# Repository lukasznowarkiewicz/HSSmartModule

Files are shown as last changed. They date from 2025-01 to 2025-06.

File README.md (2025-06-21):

# HSSmartModule

HSSM-3d-model

## Overview

This repository contains design files of Home Span Smart Module. The device is intended to use with existing electrical installation as a light controller. Initially intended to be flashed with Home Span firmware and  use with Apple Home Kit ecosystem. This will allow basic support of the implement features like outputs control, reading states form the inputs and control from other devices - aka smart home in-wall module functionality. This will allow rather quick start of the desting of the device in the files and give chance to spot potential problems right away. In the future it is planned to create custom application, with support for all implemented features in hardware like power measurement, input from presence sensor and enabling thread radio communication. The device intentionally is divided into two PCBs. This will allow independent testing, of high voltage and low voltage parts. In the future will be possible to replace low voltage PCB with with another variant - equiped with another MCU, for example NRF52840. In the future after initial bringup, set of boards could be easily redesigned as single rigid-flex PCB. 

HSSM_module_and_prog_foto

## Features

- Powered form 230VAC mains voltage
- 2x output for controlling 230VAC devices, up to 4A per channel
- 3x 230VAC inputs - two intended for ordinary switches for direct control of the outputs, additional input for motion or presence sensor
- Power usage measurement using CS5480
- ESP32-C6 SOC as main MCU and radio module
- 8MB SPI flash memory 
- Wi-Fi 6, Bluetooth 5 LE, Thread (802.15.4), Zigbee
- U.FL antenna connector

## Block diagram

## Low Voltage PCB

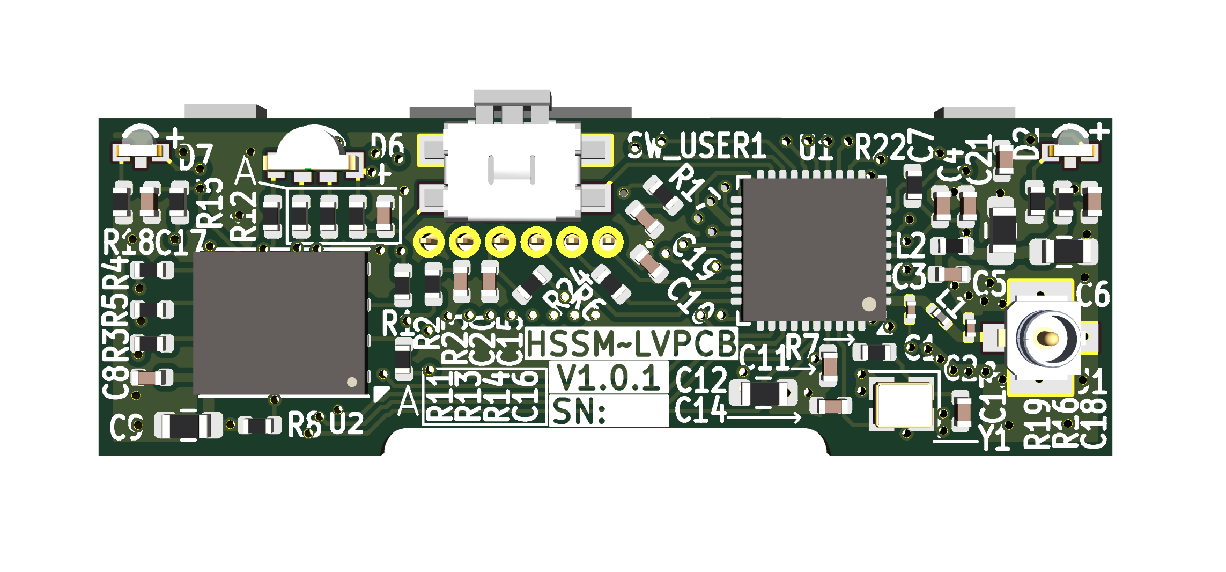
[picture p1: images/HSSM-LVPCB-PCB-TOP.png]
HSSM-LVPCB-PCB-TOP


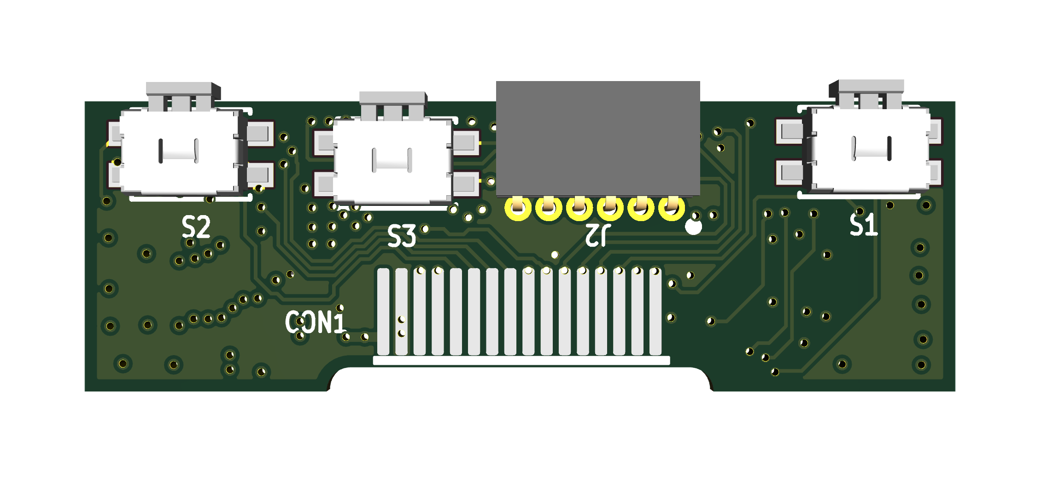
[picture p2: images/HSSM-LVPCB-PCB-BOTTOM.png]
HSSM-LVPCB-PCB-BOTTOM


### LVPCB Schematic

HSSM-LVPCB

- 3V3 power input - board is powered from HVPCB, or from programmer. If HVPCB is supplying power, 3V3 power jumper on HSSM-Prog should be left unconnected. 

- ESP32-C6 microcontroller - controlls outputs, reads values from inputs, controlls LEDs and communicate with other devices over thread, zigbee or wifi. All power inputs, crystal oscillator circuit, connection to SPI flash implemented according to datasheet.

- Antenna connector - allow connecting external 2.4 GHz antenna for wirelless connectivity

- SPI flash memory - stores ESP32-C6 program

- Additional switches and outs for debug - as program development with board powered from 230VAC seems risky, added additional switches and LEDs representing inputs and outputs on HVPCB. With those program development is possible, even without HVPCB, while LVPCB beeing powered from 3V3 LDO on programming board. 

- Programming connector - to connect HSSM-Prog, enables UART communication and puting ESP32-C6 into programming mode

- Edge connector - allows HSSM-FCB to be soldered to and connect HVPCB

## High Voltage PCB

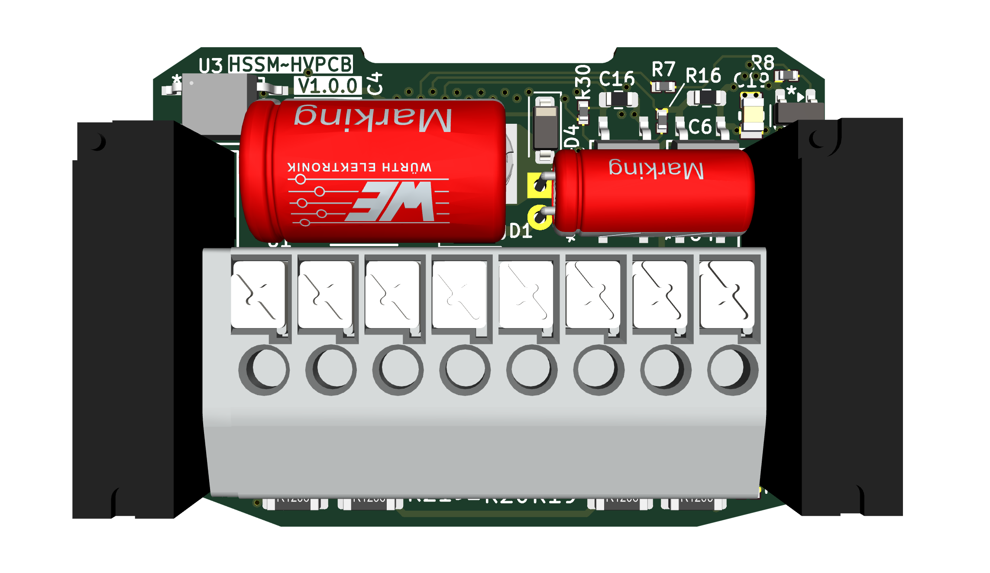
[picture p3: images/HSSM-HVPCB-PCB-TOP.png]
HSSM-HVPCB-PCB-TOP


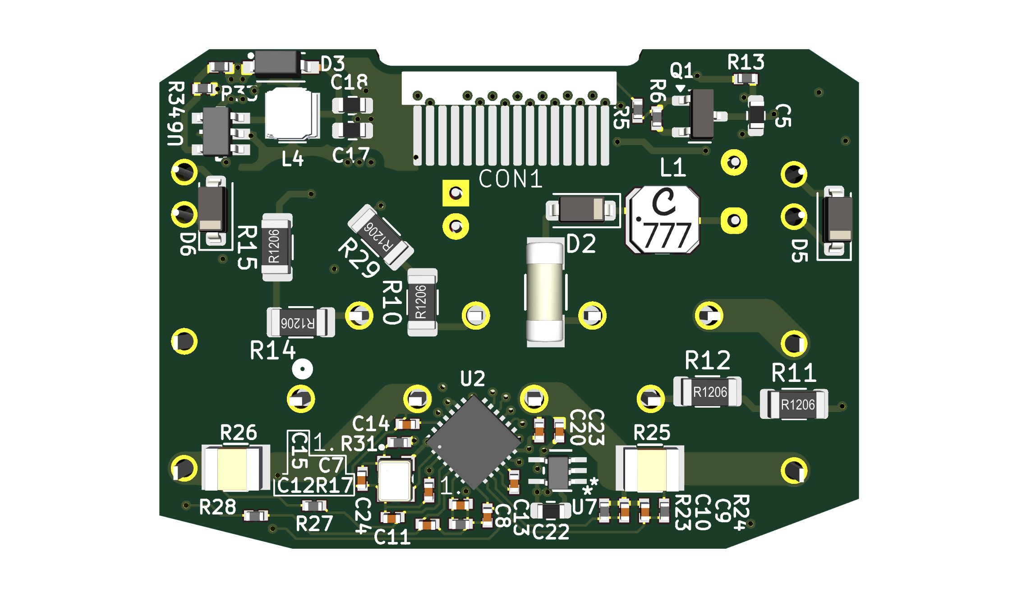
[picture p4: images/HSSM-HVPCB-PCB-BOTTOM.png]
HSSM-HVPCB-PCB-BOTTOM


<!-- ![HSSM-HVPCB-PCB-BOTTOM-IZO](images/HSSM-HVPCB-PCB-BOTTOM-IZO.png)
![HSSM-HVPCB-PCB-TOP-IZO](images/HSSM-HVPCB-PCB-TOP-IZO.png)
![HSSM-HVPCB-PCB-TOP-IZO2](images/HSSM-HVPCB-PCB-TOP-IZO2.png) -->
HSSM-HVPCB

Features:
- Outputs controls - two relays for switching 230VAC loads, internally connected to live wire terminal. Both relays powered from 12V 

- Input switches - three 230VAC inputs - for 

- 230VAC to 12VDC

- 12VDC to 3V3VDC converter

- Power measurement

## Flexible circuit board

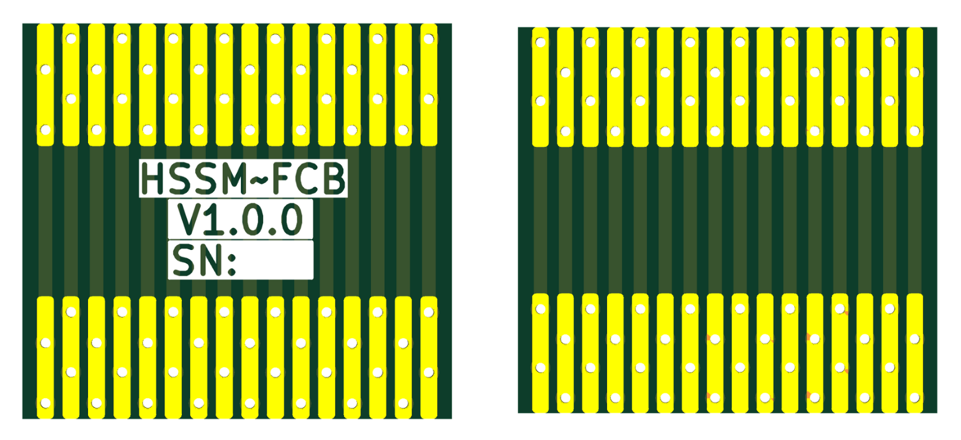
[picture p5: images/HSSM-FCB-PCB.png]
HSSM-FCB-PCB


HSSM-FCB

## HSSmartModule Programmer

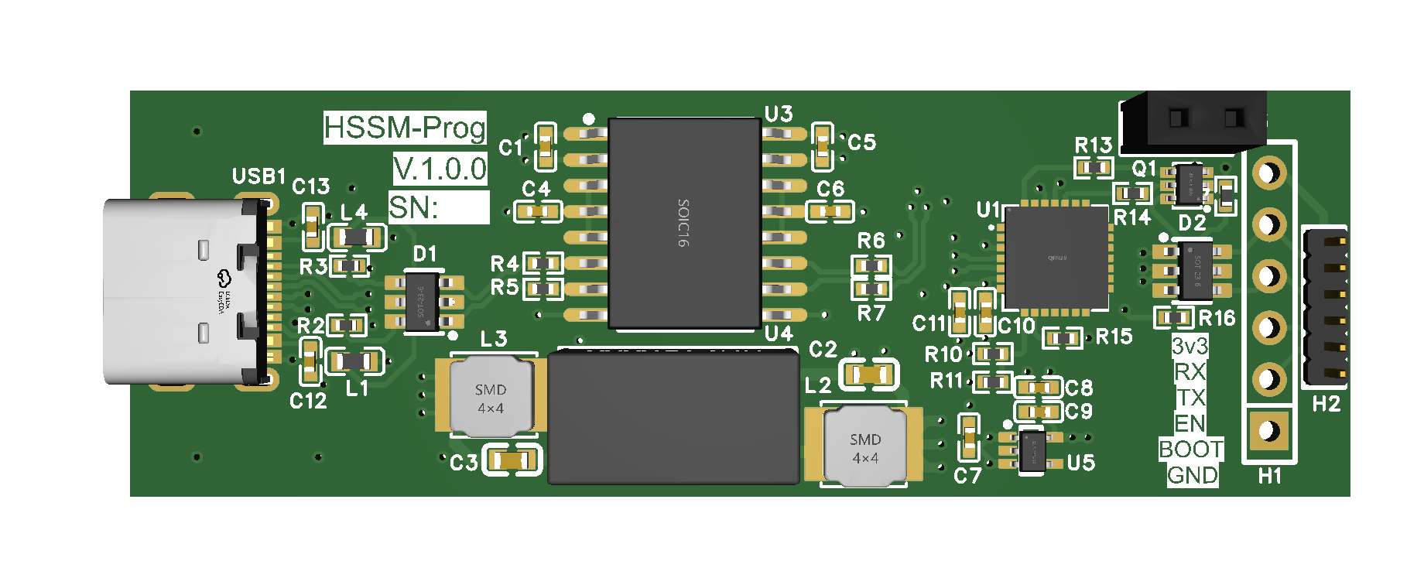
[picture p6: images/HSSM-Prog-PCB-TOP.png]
HSSM-Prog-PCB-TOP


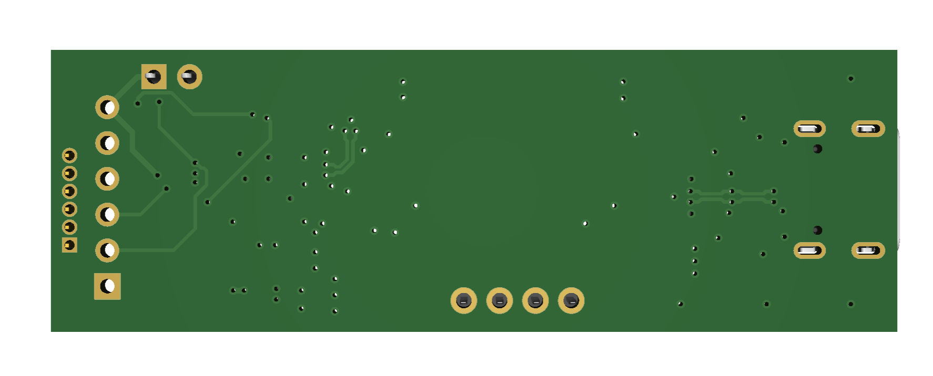
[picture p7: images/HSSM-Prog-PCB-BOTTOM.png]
HSSM-Prog-PCB-BOTTOM


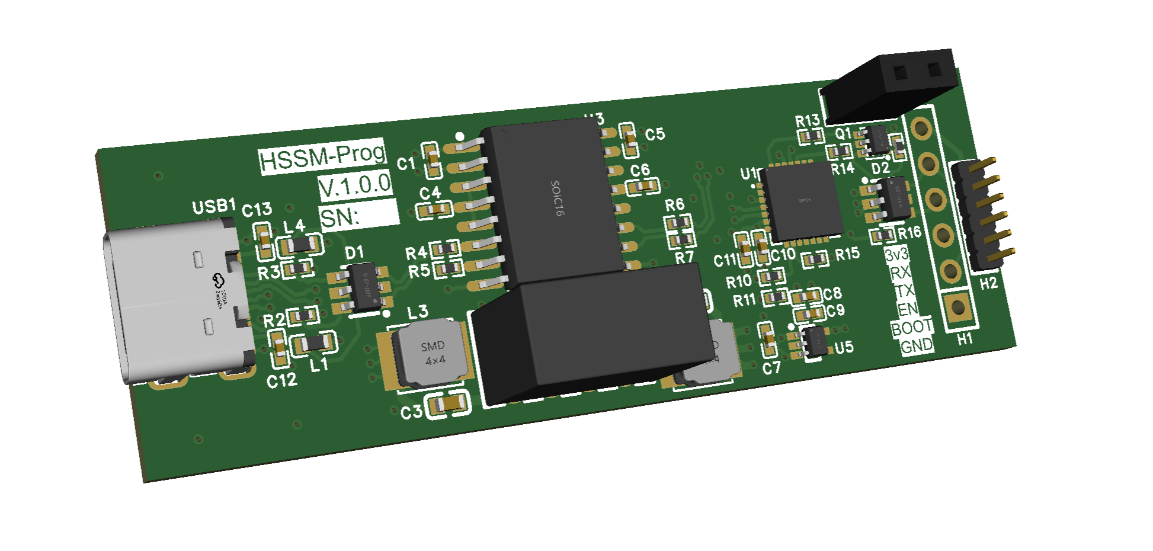
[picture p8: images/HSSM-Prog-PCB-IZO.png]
HSSM-Prog-PCB-IZO


HSSM-Prog-schematic

Features
- CP2102N USB UART converter
- Automatically put ESP32 chips into programming mode 
- power supply and data lines insulation 
- 6 poles 1.27 mm header and 6 poles 2.54 mm header for programming
- 3V3 voltage supplied to target MCU can be disable by removal of the jumper

## Manufacturing

All PCBs manufactured by JLCPCB, according to stackup set in each board's project.  

### HSSM-Prog

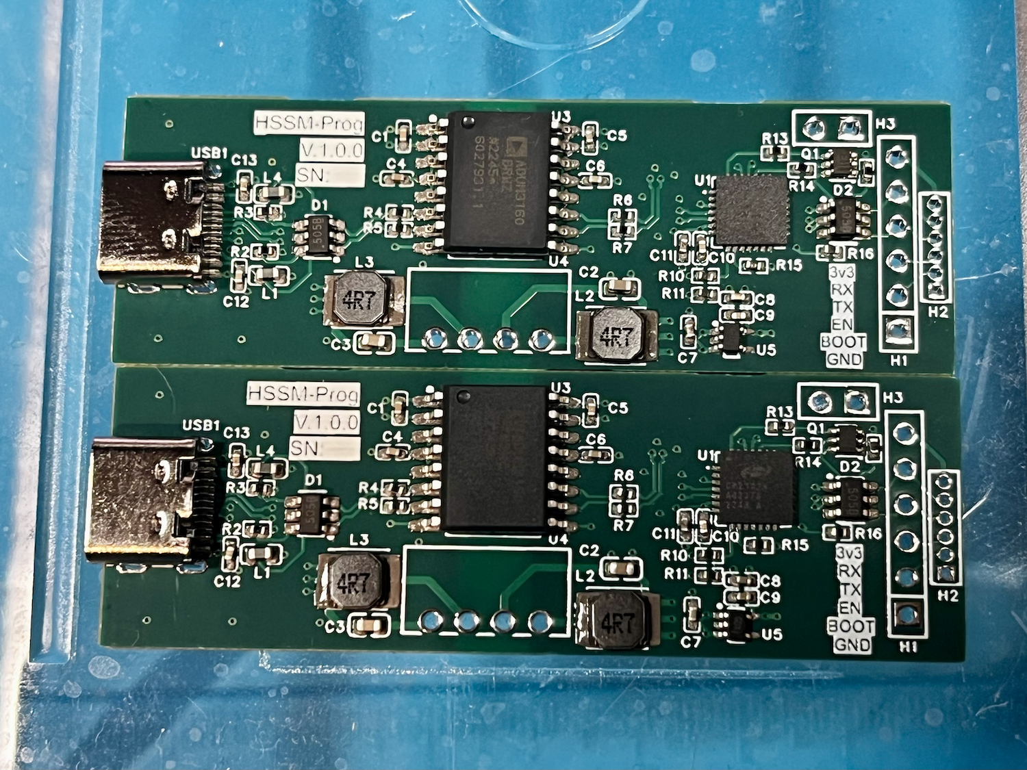
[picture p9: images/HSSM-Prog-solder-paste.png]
HSSM-Prog-solder-paste


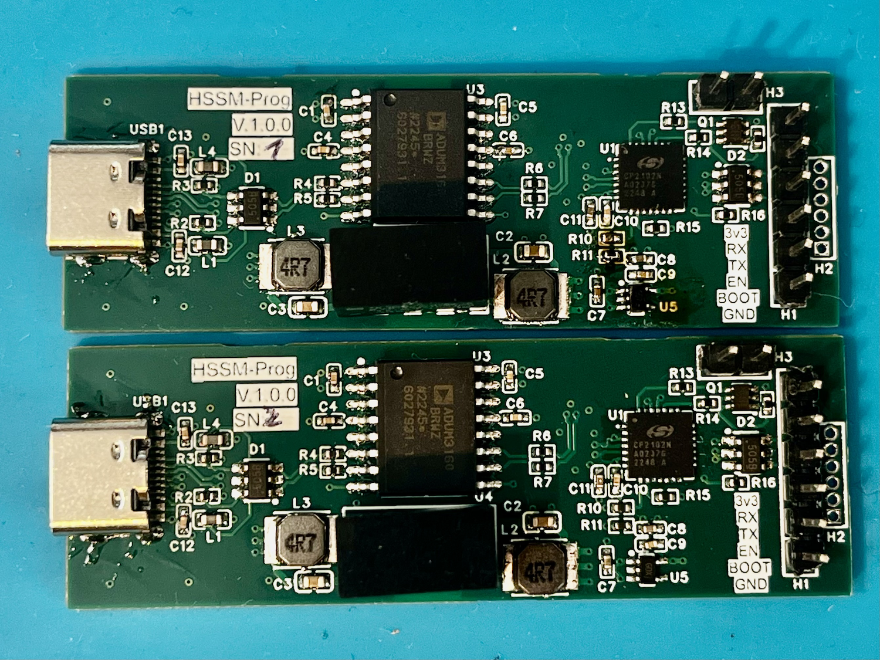
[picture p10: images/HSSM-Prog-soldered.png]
HSSM-Prog-soldered


### HSSM-LVPCB

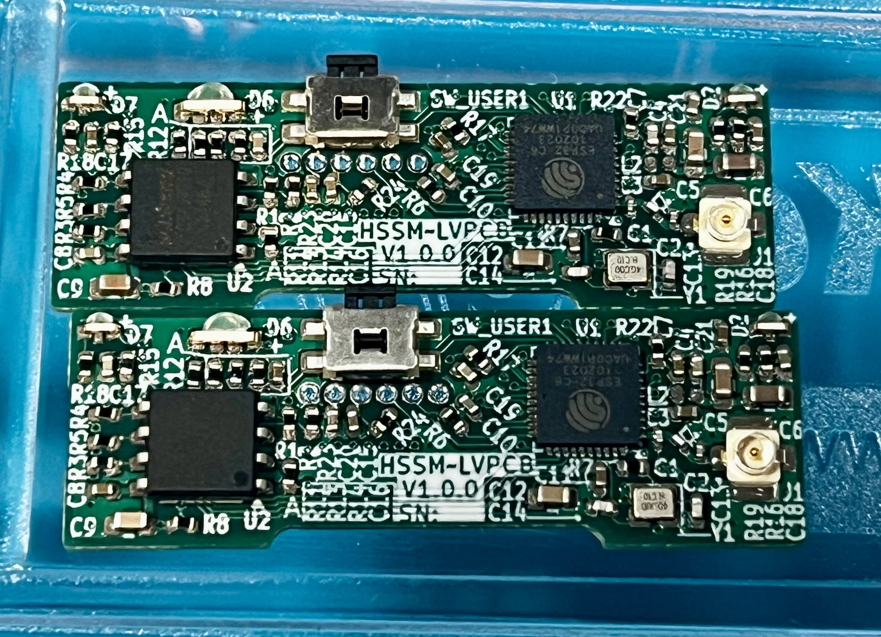
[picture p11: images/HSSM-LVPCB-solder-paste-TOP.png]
HSSM-LVPCB-solder-paste-TOP


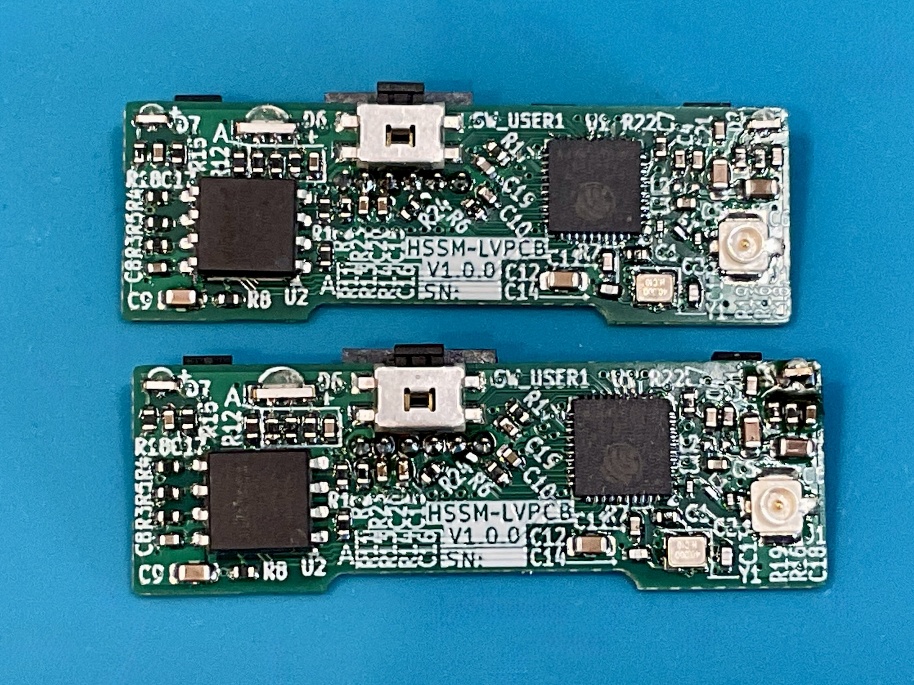
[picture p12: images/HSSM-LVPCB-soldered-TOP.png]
HSSM-LVPCB-soldered-TOP


### HSSM-HVPCB

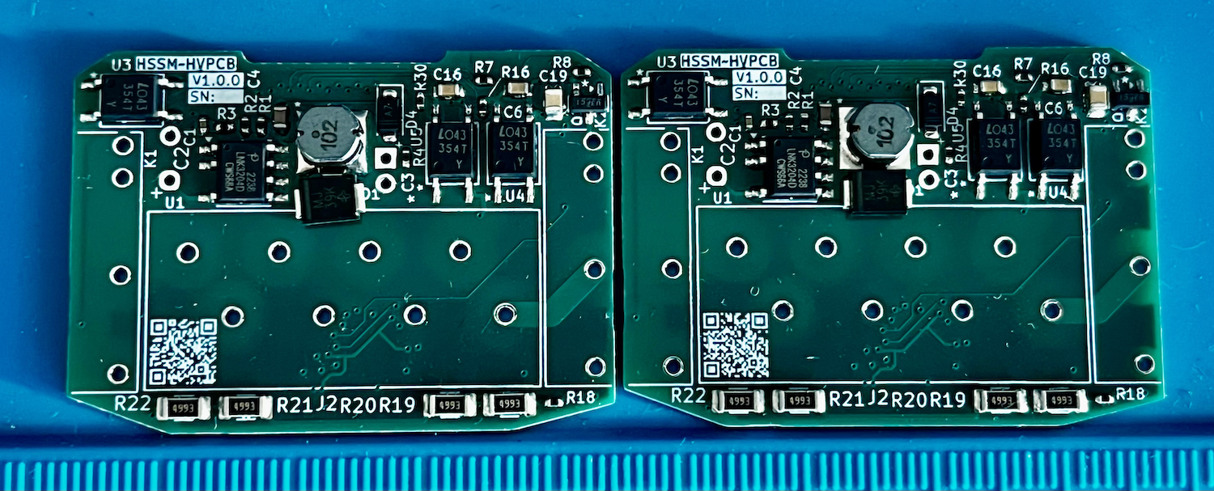
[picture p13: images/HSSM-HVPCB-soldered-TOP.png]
HSSM-HVPCB-soldered-TOP


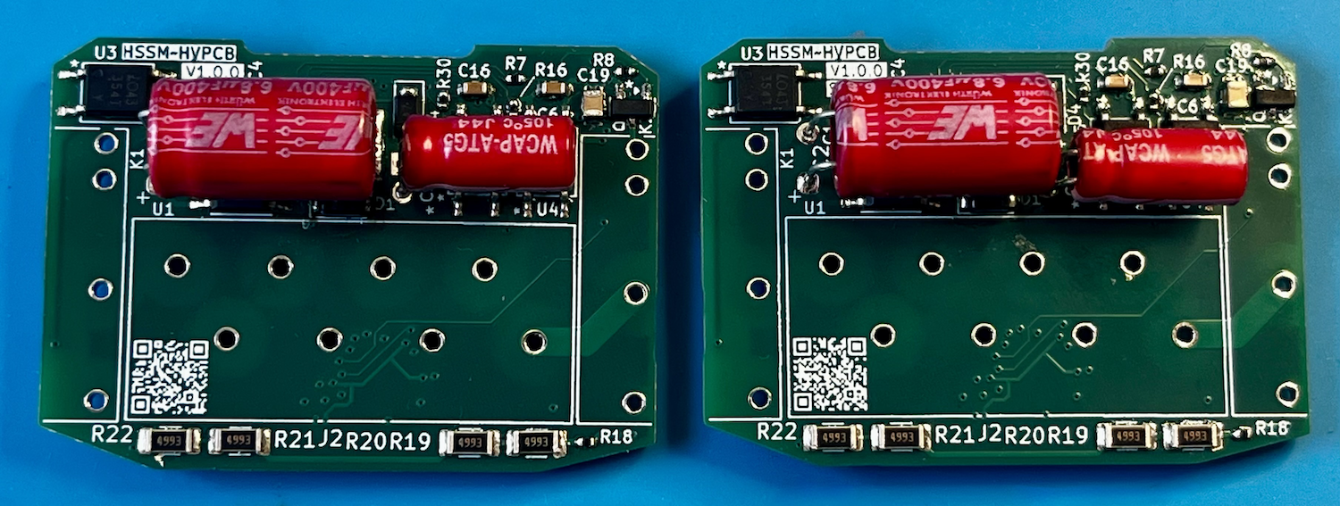
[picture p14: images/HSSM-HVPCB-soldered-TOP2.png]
HSSM-HVPCB-soldered-TOP2


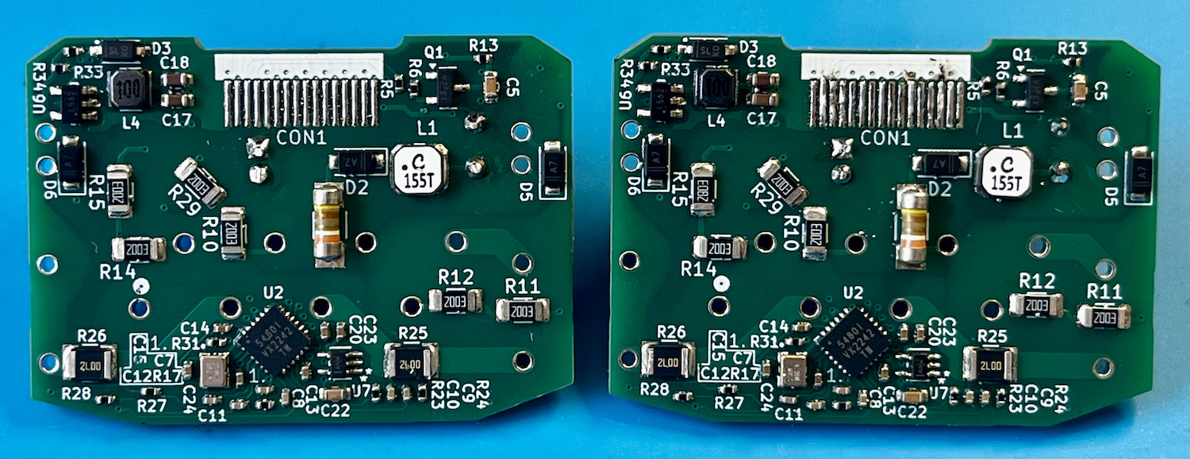
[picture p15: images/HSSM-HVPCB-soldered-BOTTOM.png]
HSSM-HVPCB-soldered-BOTTOM


## Boards bring up 

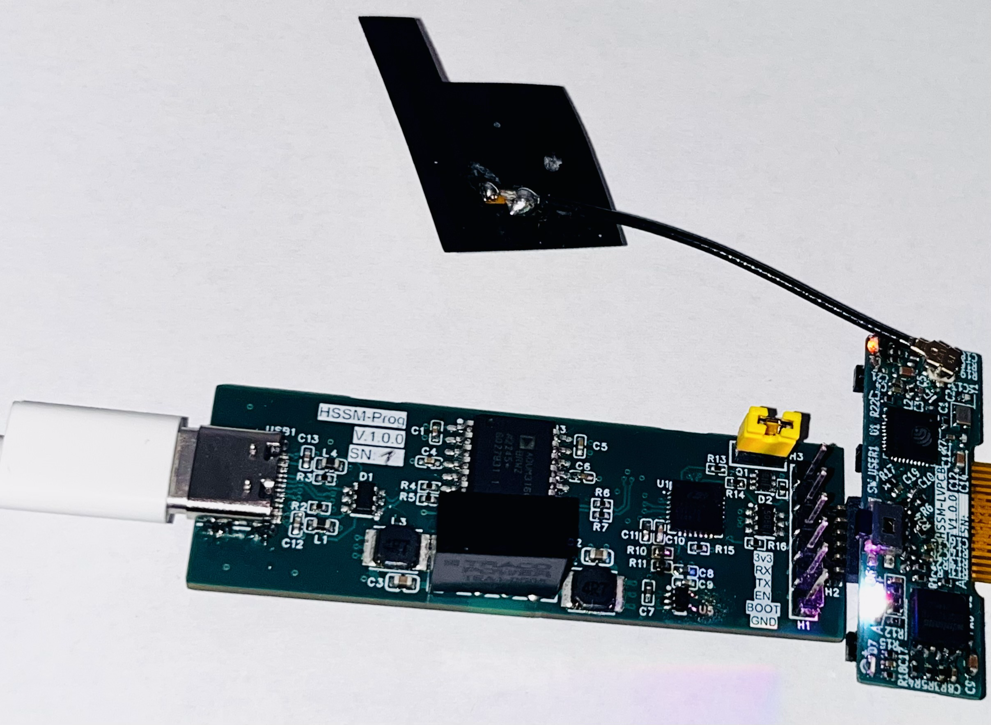
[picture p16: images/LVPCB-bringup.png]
LVPCB-bringup


HVPCB-bringup

## HSSM device assembly

HSSM_module_foto
HSSM_module_foto2

### Firmware for boards testing

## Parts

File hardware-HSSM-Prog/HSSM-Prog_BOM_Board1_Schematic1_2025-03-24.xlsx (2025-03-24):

HSSM-Prog_BOM_Board1_Schematic1_2025-03-24
No. | Designator | Quantity | Manufacturer Part | Manufacturer
1 | C1,C4,C5,C6,C9,C10,C12,C13 | 8 | CL05B104KO5NNNC | SAMSUNG(三星)
2 | C2,C3 | 2 | CL10A475KO8NNNC | SAMSUNG(三星)
3 | C7,C8,C11 | 3 | CL05A105KA5NQNC | SAMSUNG(三星)
4 | D1,D2 | 2 | SP0505BAHTG | Littelfuse(美国力特)
5 | H1 | 1 | 2.54-1*6P母 | BOOMELE(博穆精密)
6 | H2 | 1 | 1271WV-6P | HanElectricity(瀚源)
7 | H3 | 1 | 2.54-1*2P母 | BOOMELE(博穆精密)
8 | L1,L4 | 2 | BLM18PG121SN1D | muRata(村田)
9 | L2,L3 | 2 | FNR4012S4R7MT | cjiang(长江微电)
10 | Q1 | 1 | UMH3NTN | ROHM(罗姆)
11 | R2,R3,R13,R14 | 4 | RCA025K1JLF | HKR(香港电阻)
12 | R4,R5,R6,R7,R16,R17 | 6 | AC0402FR-0724RL | YAGEO(国巨)
13 | R10 | 1 | 0402WGF2202TCE | UNI-ROYAL(厚声)
14 | R11 | 1 | 0402WGF4702TCE | UNI-ROYAL(厚声)
15 | R15 | 1 | 0402WGF1001TCE | UNI-ROYAL(厚声)
16 | U1 | 1 | CP2102N-A02-GQFN28R | SKYWORKS/SILICON LABS(芯科)
17 | U3 | 1 | ADUM3160BRWZ-RL | ADI(亚德诺)
18 | U4 | 1 | HLK-1D0505A | HI-LINK(海凌科)
19 | U5 | 1 | ME6211C33R5G | MICRONE(南京微盟)
20 | USB1 | 1 | UC09-0B16F00P11 | BXCONN(宝讯)

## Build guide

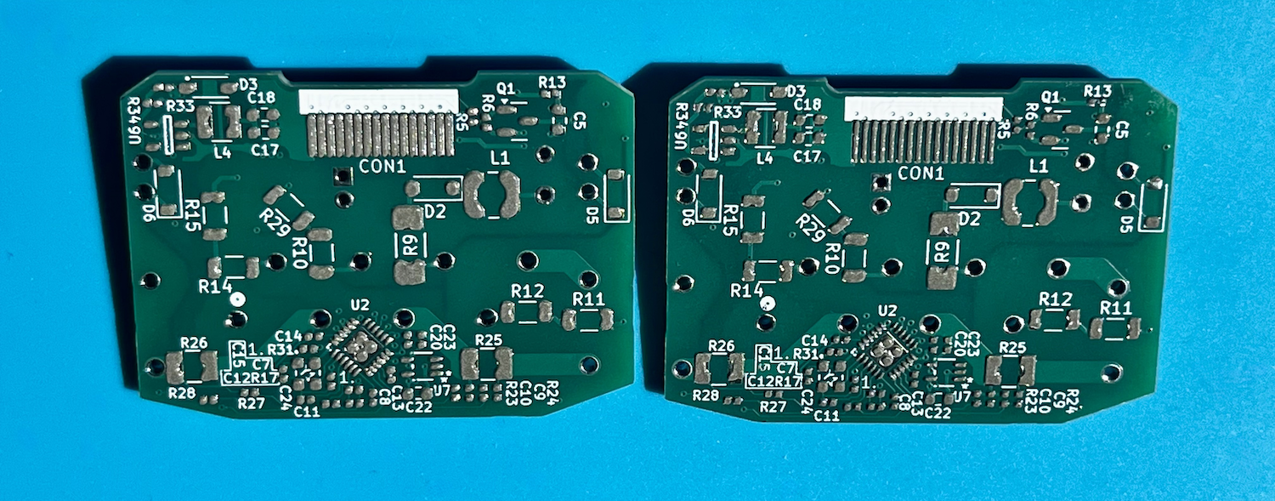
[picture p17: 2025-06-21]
images/HSSM-HVPCB-solder-paste-BOTTOM.png

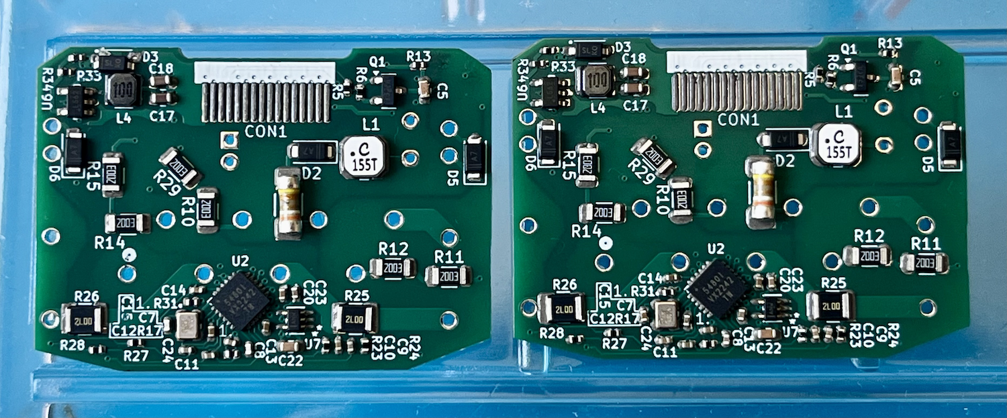
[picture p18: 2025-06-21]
images/HSSM-HVPCB-solder-paste-BOTTOM2.png

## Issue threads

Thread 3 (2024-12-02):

Prepare schematic HSSM-HVPCB

lukasznowarkiewicz, 2024-12-02:
In https://github.com/lukasznowarkiewicz/HSSmartModule/issues/1 and https://github.com/lukasznowarkiewicz/HSSmartModule/issues/2 general concept of the device has been introduced. Subject of this task is to prepare components and schematic for the high voltage part.

Closed 2025-06-21.

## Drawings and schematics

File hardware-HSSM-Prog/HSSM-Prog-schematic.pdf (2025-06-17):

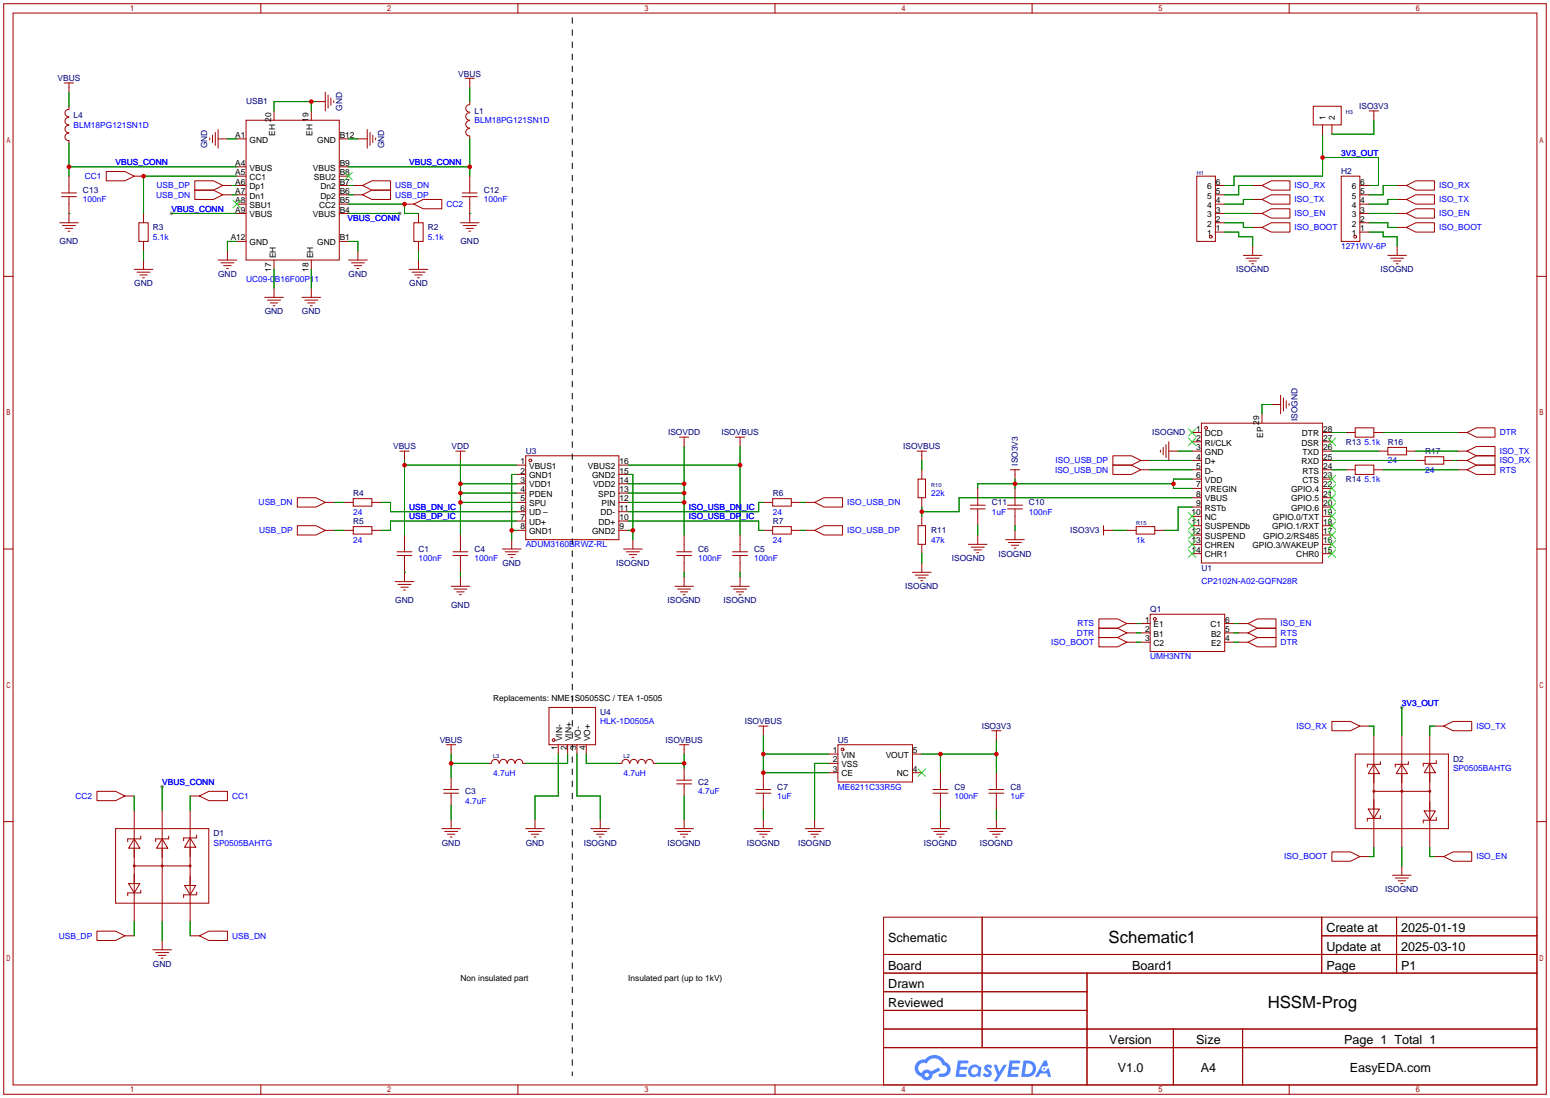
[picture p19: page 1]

DD+ 10 DD- 11 PIN 12 SPD 13 VDD2 14 GND2 15 VBUS2 16

Schematic | Schematic1 | Create at | 2025-01-19

Update at | 2025-03-10

Board | Board1 | Page | P1
Drawn | | HSSM-Prog
Reviewed

Version | Size | Page 1 Total 1
V1.0 | A4 | EasyEDA.com

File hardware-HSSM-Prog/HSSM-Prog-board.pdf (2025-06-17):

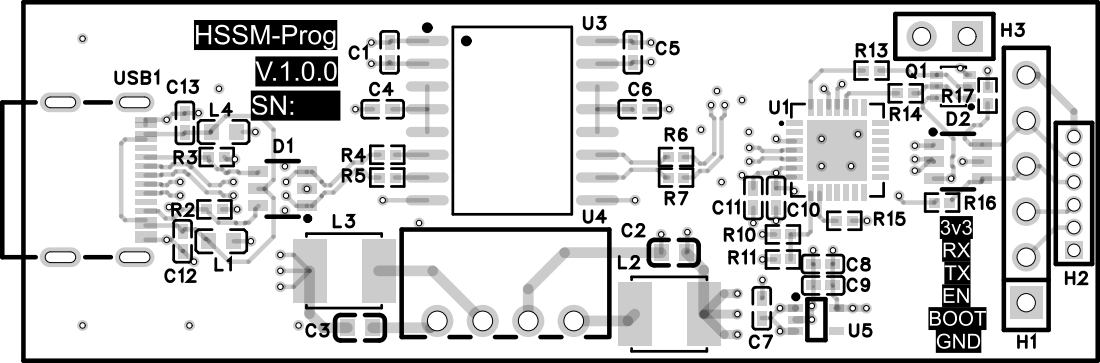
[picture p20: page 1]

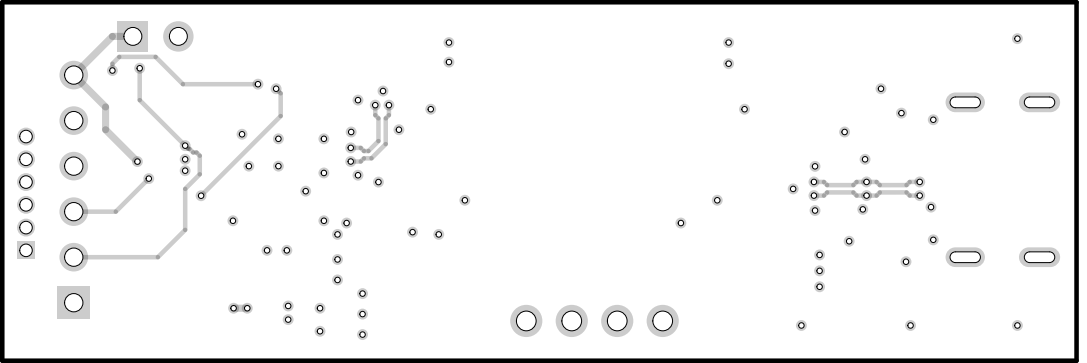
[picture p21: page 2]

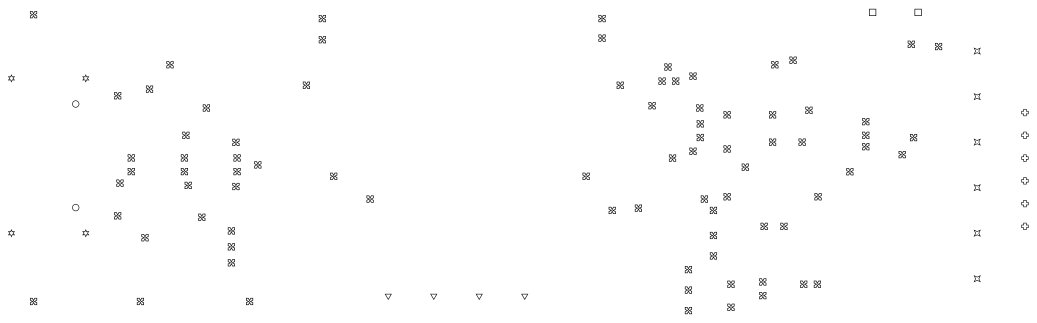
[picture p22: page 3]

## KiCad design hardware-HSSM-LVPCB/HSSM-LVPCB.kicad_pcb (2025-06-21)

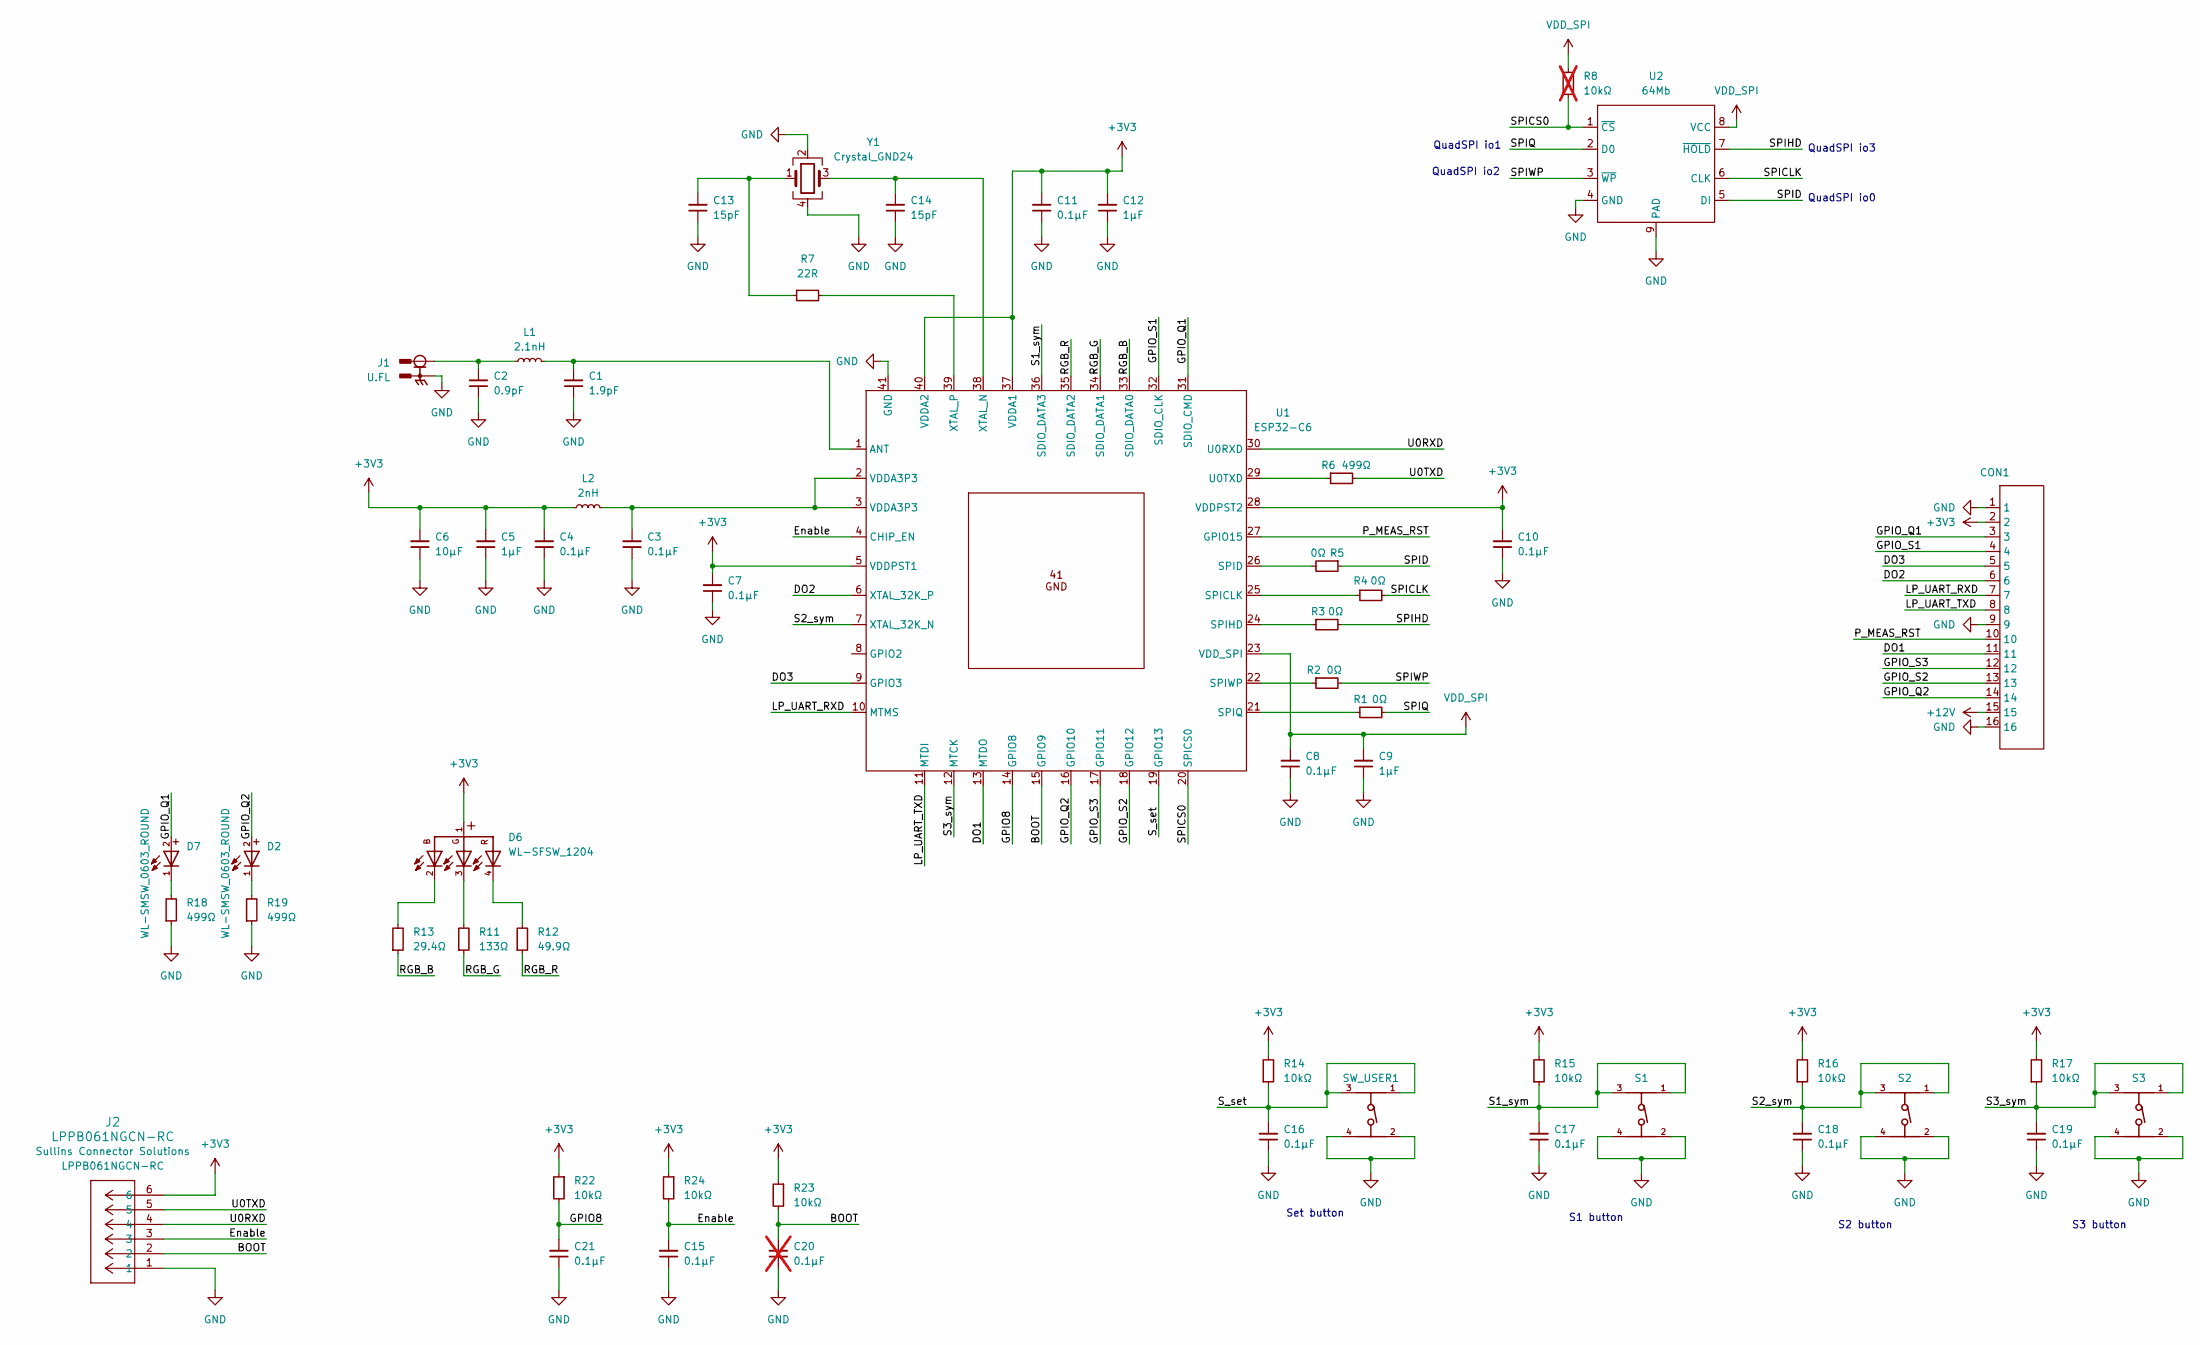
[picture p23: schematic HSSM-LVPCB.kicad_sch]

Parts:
C1: C_1p9_0.05pct_50V_0201_GRM0335C1H1R9WA01D; C_0201; MPN GRM0335C1H1R9WA01D
C2: C_0p9_0.05pct_50V_0201_GRM0335C1HR90WA01D; C_0201; MPN GRM0335C1HR90WA01D
C3, C4, C7, C8, C10, C11, C15, C16, C17, C18, C19, C21: C_0u1_10pct_50V_0402_GRM155R71H104KE14D; C_0402; MPN GRM155R71H104KE14D
C5, C9, C12: C_1uF_10pct_16V_0603_GCM188R71C105KA64D; C_0603; MPN GCM188R71C105KA64D
C6: C_10u_20pct_16V_0603_GRM188R61C106MA73D; C_0603; MPN GRM188R61C106MA73D
C13, C14: C_15pF_1pct_50V_0402_C0402C150F5GACAUTO; C_0402; MPN C0402C150F5GACAUTO
C20: C_0u1_10pct_50V_0402_GRM155R71H104KE14D; C_0402; MPN GRM155R71H104KE14D; not fitted
CON1: FFC_solder_connector_16pos
D2, D7: WL-SMSW_0603_ROUND; 155060AS73200; MPN 155060AS73200
D6: WL-SFSW_1204; 155124M173200; MPN 155124M173200
J1: UFL_R_SMT_1_10; CONMHF1-SMD-T; MPN U.FL-R-SMT-1(10)
J2: LPPB061NGCN-RC; MPN LPPB061NGCN-RC
L1: L_2n1_2000mA_0201_LQP03HQ2N1B02D; L_0201; MPN LQP03HQ2N1B02D
L2: L_2nH_0402_ MHQ1005075HA2N0BTD25; L_0402; MPN MHQ1005075HA2N0BTD25
R1, R2, R3, R4, R5: R_0R_5pct_0402_RC0402JR-070RL; R_0402; MPN RC0402JR-070RL
R6, R18, R19: R_499R_1pct_0402_RC0402FR-07499RL; R_0402; MPN RC0402FR-07499RL
R7: R_22R_1pct_0402_CRCW040222R0FKED; R_0402; MPN CRCW040222R0FKED
R8: R_10k_1pct_0402_RC0402FR-0710KL; R_0402; MPN RC0402FR-0710KL; not fitted
R11: R_133R_1pct_0402_CRCW0402133RFKED; R_0402; MPN CRCW0402133RFKED
R12: R_49R9_1pct_0402_CRCW040249R9FKED; R_0402; MPN CRCW040249R9FKED
R13: R_29R4_1pct_0402_CRCW040229R4FKED; R_0402; MPN CRCW040229R4FKED
R14, R15, R16, R17, R22, R23, R24: R_10k_1pct_0402_RC0402FR-0710KL; R_0402; MPN RC0402FR-0710KL
S1, S2, S3: 434331045822; MPN 434331045822
SW_USER1: 434331045822; MPN 434331045822
U1: ESP32-C6; QFN-40-1EP_5x5mm_P0.4mm_EP3.6x3.6mm; MPN ESP32-C6
U2: W25Q64JVZPIM_WSON-8; WSON-8-1EP_6x5mm_P1.27mm_EP3.4x4.3mm; MPN W25Q64JVZPIM
Y1: Crystal_GND24; Crystal_SMD_2016-4Pin_2.0x1.6mm; MPN CN4040M00010001

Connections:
+3V3: C4.2, C5.2, C6.2, C7.2, C10.2, C11.2, C12.2, CON1.2, D6.1, J2.6, L2.1, R14.2, R15.2, R16.2, R17.2, R22.1, R23.1, R24.1, U1.5 (VDDPST1), U1.28 (VDDPST2), U1.37 (VDDA1), U1.40 (VDDA2)
+12V: CON1.15
/BOOT: C20.2, J2.2, R23.2, U1.15 (GPIO9)
/DO1: CON1.11, U1.13 (MTDO)
/DO2: CON1.6, U1.6 (XTAL_32K_P)
/DO3: CON1.5, U1.9 (GPIO3)
/Enable: C15.2, J2.3, R24.2, U1.4 (CHIP_EN)
/GPIO8: C21.2, R22.2, U1.14 (GPIO8)
/GPIO_Q1: CON1.3, D7.2, U1.31 (SDIO_CMD)
/GPIO_Q2: CON1.14, D2.2, U1.16 (GPIO10)
/GPIO_S1: CON1.4, U1.32 (SDIO_CLK)
/GPIO_S2: CON1.13, U1.18 (GPIO12)
/GPIO_S3: CON1.12, U1.17 (GPIO11)
/LP_UART_RXD: CON1.7, U1.10 (MTMS)
/LP_UART_TXD: CON1.8, U1.11 (MTDI)
/P_MEAS_RST: CON1.10, U1.27 (GPIO15)
/RGB_B: R13.1, U1.33 (SDIO_DATA0)
/RGB_G: R11.1, U1.34 (SDIO_DATA1)
/RGB_R: R12.1, U1.35 (SDIO_DATA2)
/S1_sym: C17.2, R15.1, S1.1, S1.3, U1.36 (SDIO_DATA3)
/S2_sym: C18.2, R16.1, S2.1, S2.3, U1.7 (XTAL_32K_N)
/S3_sym: C19.2, R17.1, S3.1, S3.3, U1.12 (MTCK)
/SPICLK: R4.2, U2.6 (CLK)
/SPICS0: R8.1, U1.20 (SPICS0), U2.1 (~CS)
/SPID: R5.1, U2.5 (DI)
/SPIHD: R3.2, U2.7 (~HOLD)
/SPIQ: R1.2, U2.2 (D0)
/SPIWP: R2.2, U2.3 (~WP)
/S_set: C16.2, R14.1, SW_USER1.1, SW_USER1.3, U1.19 (GPIO13)
/U0RXD: J2.4, U1.30 (U0RXD)
/U0TXD: J2.5, R6.2
GND: C1.1, C2.1, C3.1, C4.1, C5.1, C6.1, C7.1, C8.1, C9.1, C10.1, C11.1, C12.1, C13.1, C14.1, C15.1, C16.1, C17.1, C18.1, C19.1, C20.1, C21.1, CON1.1, CON1.9, CON1.16, J1.S1, J1.S2, J1.S3, J2.1, R18.1, R19.1, S1.2, S1.4, S2.2, S2.4, S3.2, S3.4, SW_USER1.2, SW_USER1.4, U1.41 (GND), U2.4 (GND), U2.9 (PAD), Y1.2, Y1.4
unnamed: C2.2, J1.1, L1.1
unnamed: C3.2, L2.2, U1.2 (VDDA3P3), U1.3 (VDDA3P3)
unnamed: C13.2, R7.1, Y1.1
unnamed: D2.1, R19.2
unnamed: D6.2, R13.2
unnamed: D6.3, R11.2
unnamed: D6.4, R12.2
unnamed: D7.1, R18.2
unnamed: C1.2, L1.2, U1.1 (ANT)
unnamed: R4.1, U1.25 (SPICLK)
unnamed: R5.2, U1.26 (SPID)
unnamed: R3.1, U1.24 (SPIHD)
unnamed: R1.1, U1.21 (SPIQ)
unnamed: R2.1, U1.22 (SPIWP)
unnamed: R6.1, U1.29 (U0TXD)
unnamed: C14.2, U1.38 (XTAL_N), Y1.3
unnamed: R7.2, U1.39 (XTAL_P)
VDD_SPI: C8.2, C9.2, R8.2, U1.23 (VDD_SPI), U2.8 (VCC)

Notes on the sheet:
QuadSPI io3
Set button
S1 button
QuadSPI io2
QuadSPI io1
QuadSPI io0
S2 button
S3 button

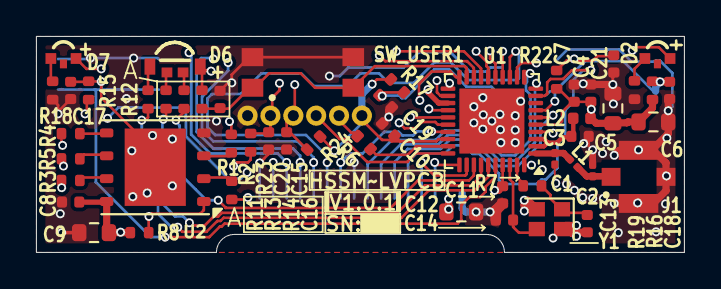
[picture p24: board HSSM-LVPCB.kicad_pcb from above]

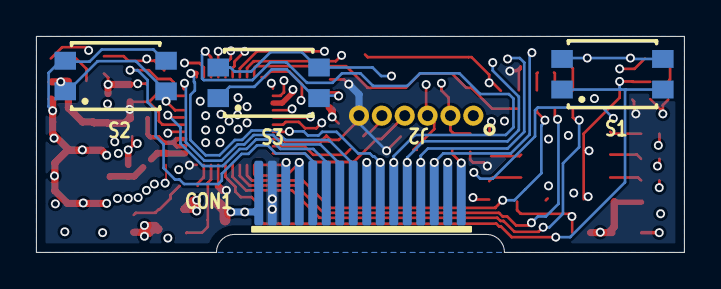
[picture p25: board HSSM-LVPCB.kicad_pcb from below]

Board: 4 copper layers, 36.0 x 12.0 mm, 56 parts (5 on the bottom side), 49 nets.

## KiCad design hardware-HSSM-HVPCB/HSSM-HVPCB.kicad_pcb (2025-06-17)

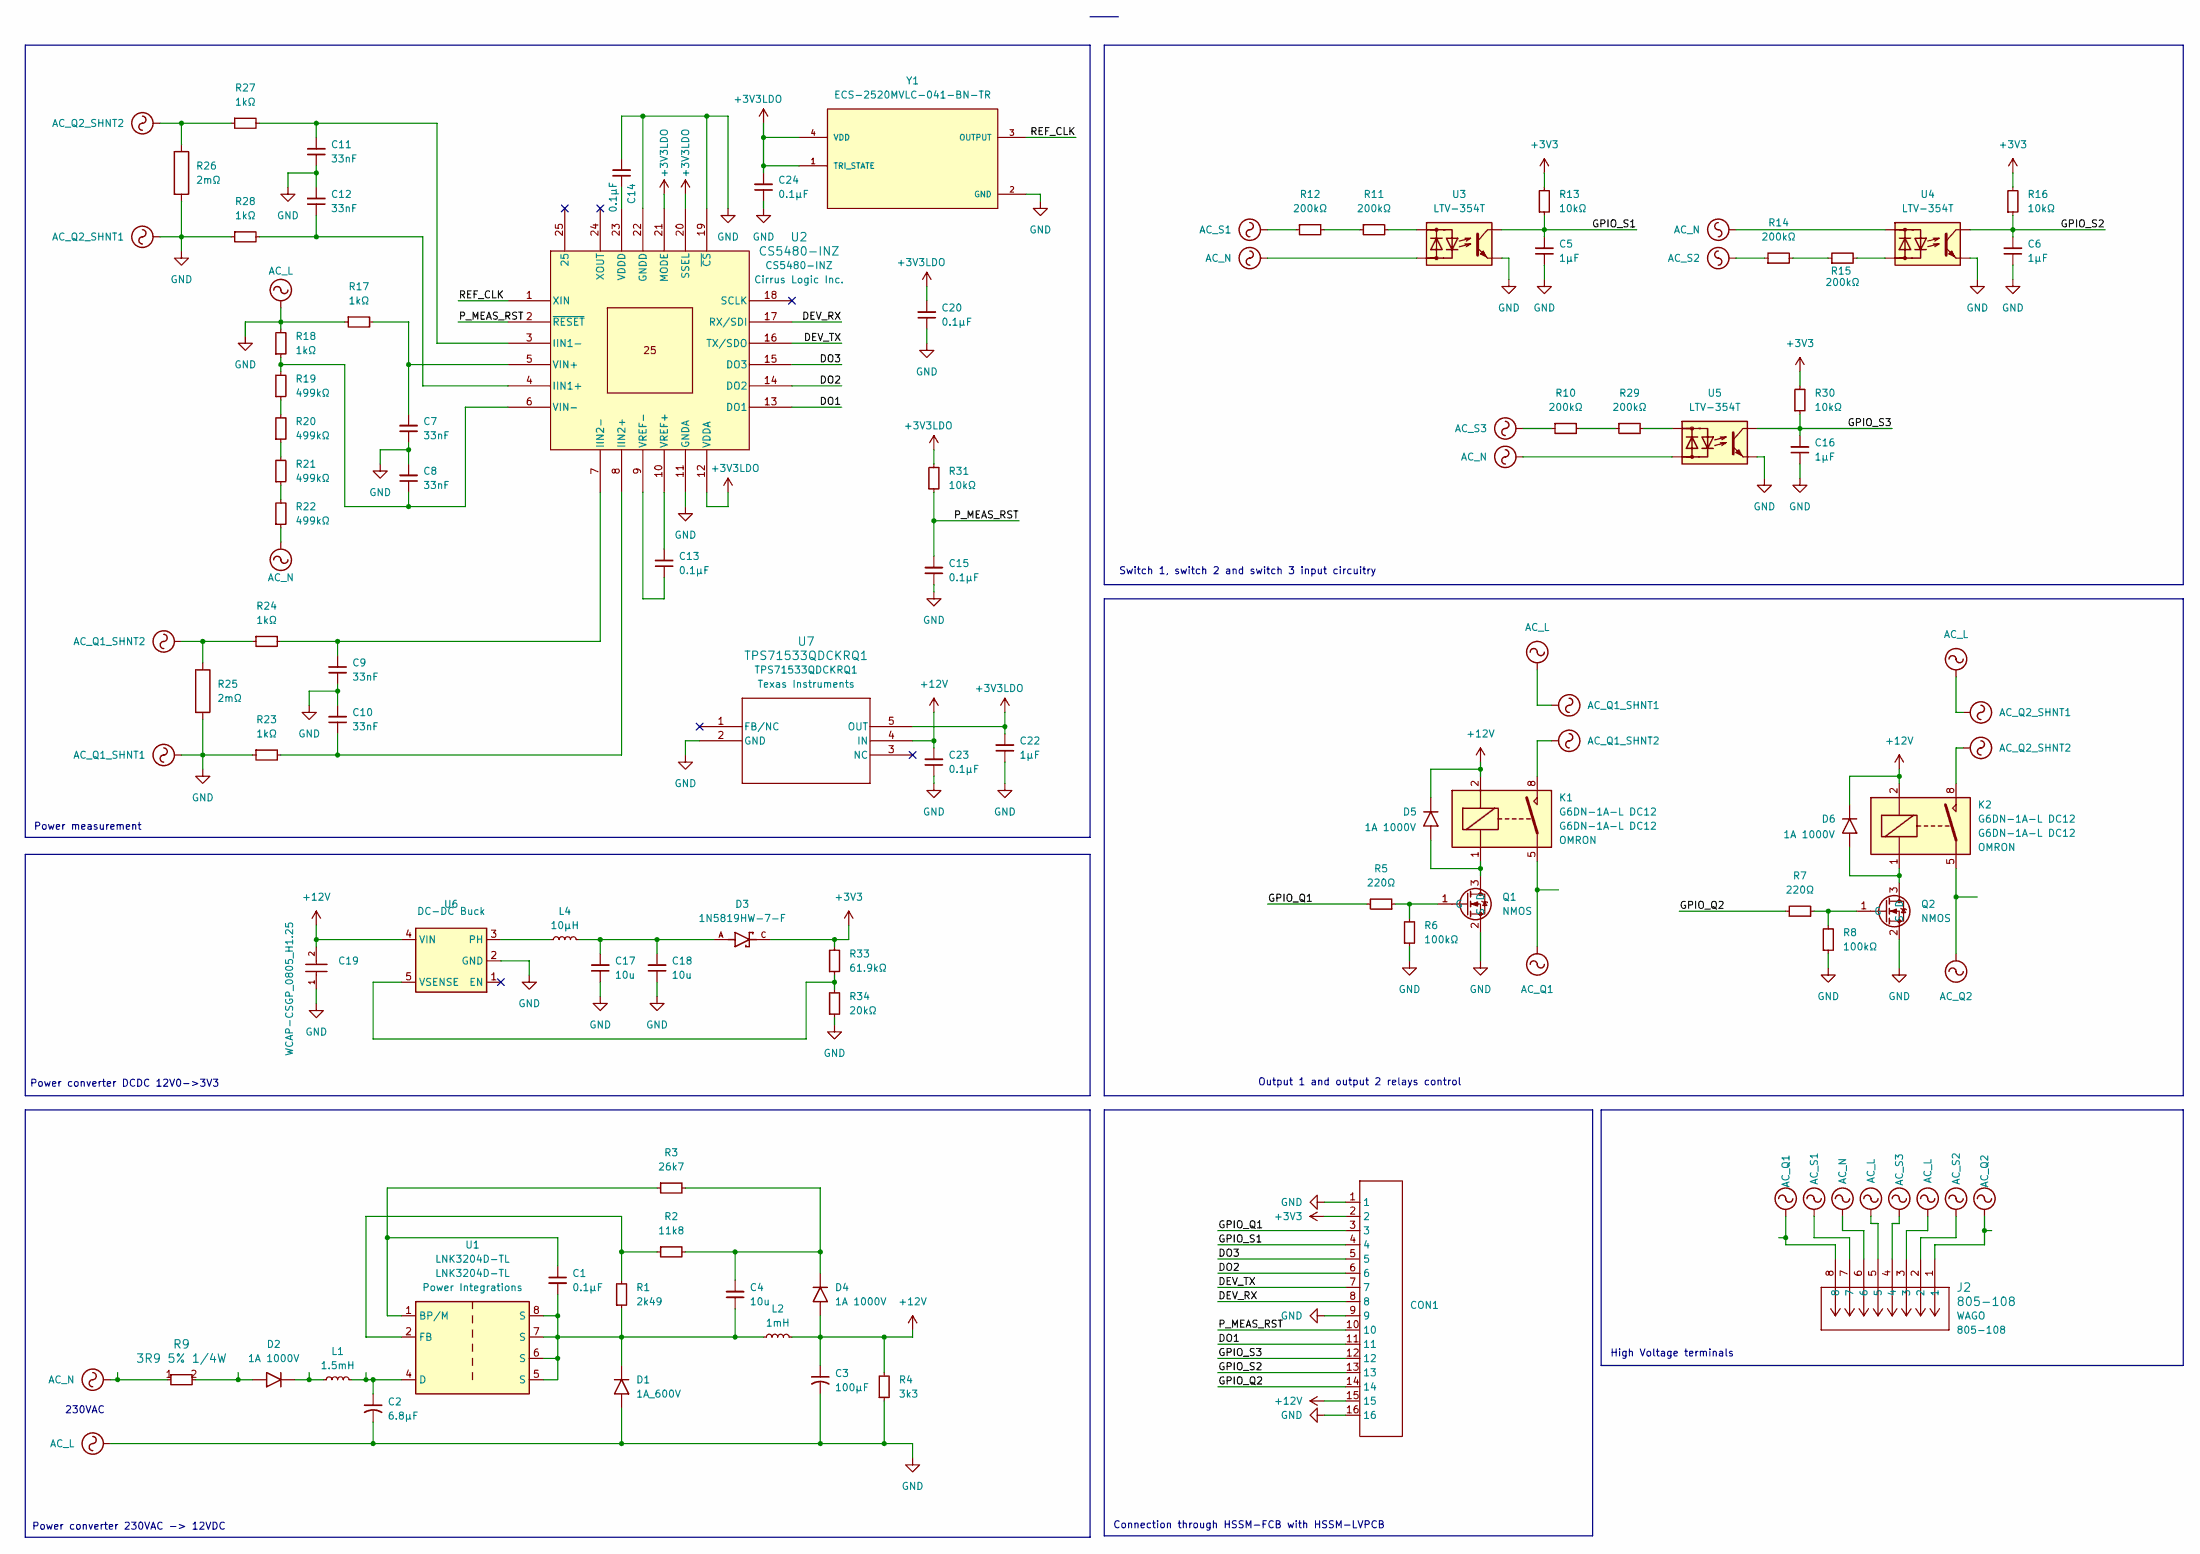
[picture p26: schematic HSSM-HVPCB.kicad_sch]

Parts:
C1: C_0u1_10pct_16V_0402_GRM155R71C104KA88J; C_0402; MPN GRM155R71C104KA88J
C2: C_6u8_20pct_400V_8mm_WCAP-ATG5_860021374009; 860021374009; MPN 860021374009
C3: C_100uF_20pct_16V_5mm_WCAP-ATG5_860020372006; 860020372006; MPN 860020372006
C4, C17, C18: C_10u_10pct_25V_0603_GRM188R61E106KA73D; C_0603; MPN GRM188R61E106KA73D
C5, C6, C16, C22: C_1uF_10pct_16V_0603_GCM188R71C105KA64D; C_0603; MPN GCM188R71C105KA64D
C7, C8, C9, C10, C11, C12: C_33nF_10pct_50V_0402_CC0402KRX7R9BB333; C_0402; MPN CC0402KRX7R9BB333
C13, C14, C15, C20, C23, C24: C_0u1_10pct_50V_0402_GRM155R71H104KE14D; C_0402; MPN GRM155R71H104KE14D
C19: WCAP-CSGP_0805_H1.25; 885012107018; MPN 885012107018
CON1: FFC_solder_connector_16pos
D1: D_rect_1A_600V_SOD123FL_ERL1J; D_SOD123FL; MPN ERL1J
D2, D4, D5, D6: D_rect_1A_1000V_SOD123_1N4007W; D_SOD123; MPN 1N4007W
D3: 1N5819HW-7-F; PARTREV 18-2
J2: 805-108; MPN 805-108
K1, K2: G6DN-1A-L DC12; RELAY_G6DN-1A_OMR; MPN G6DN-1A-L DC12
L1: L_1.5mH_20pct_1500uH_LPS4012-155MRC; LPS4012; MPN LPS4012-155MRC
L2: L_1mH_10pct_SDR0503-102KL; SDR0503; MPN SDR0503-102KL
L4: L_10uH_20pct_1A_SDCL1V3012-100M-R; L_3012; MPN SDCL1V3012-100M-R
Q1, Q2: Q_NMOS_SOT-23_IRLML6344; SOT-23; MPN IRLML6344
R1: R_2k49_1pct_0402_RC0402FR-072K49L; R_0402; MPN RC0402FR-072K49L
R2: R_11k8_1pct_0402_RC0402FR-0711K8L; R_0402; MPN RC0402FR-0711K8L
R3: R_26k7_0.1pct_0402_CPF0402B26K7E1; R_0402; MPN CPF0402B26K7E1
R4: R_3k3_5pct_0402_RC0402JR-073K3L; R_0402; MPN RC0402JR-073K3L
R5, R7: R_220R_1pct_0402_RC0402FR-07220RL; R_0402; MPN RC0402FR-07220RL
R6, R8: R_100k_1pct_0402_RC0402FR-07100KL; R_0402; MPN RC0402FR-07100KL
R9: 3R9 5% 1/4W; LCM0207B03908JBP00; MPN LCM0207B03908JBP00
R10, R11, R12, R14, R15, R29: R_200k_0.1pct_1206_VT1206BRD07200KL; R_1206_HV; MPN VT1206BRD07200KL
R13, R16, R30, R31: R_10k_1pct_0402_RC0402FR-0710KL; R_0402; MPN RC0402FR-0710KL
R17, R18, R23, R24, R27, R28: R_1k_1pct_0402_CRCW04021K00FKED; R_0402; MPN CRCW04021K00FKED
R19, R20, R21, R22: R_499k_1pct_1206_KTR18EZPF4993; R_1206_HV; MPN KTR18EZPF4993
R25, R26: R_Shunt_2mOhm_1pct_1210_PMR25HZPFV2L00; R_1210; MPN PMR25HZPFV2L00
R33: R_61k9_1pct_0402_RC0402FR-0761K9L; R_0402; MPN RC0402FR-0761K9L
R34: R_20k_1pct_0402_RC0402FR-0720KL; R_0402; MPN RC0402FR-0720KL
U1: LNK3204D-TL; PowerIntegrations_SO-8C; MPN LNK3204D-TL
U2: CS5480-INZ; CIR-QFN-24; MPN CS5480-INZ
U3, U4, U5: LTV-354T; MPN LTV-354T
U6: TPS560200DBVR_SOIC_6_TI; SOIC_6; MPN TPS560200DBVR
U7: TPS71533QDCKRQ1; MPN TPS71533QDCKRQ1
Y1: ECS-2520MVLC-041-BN-TR; MPN ECS-2520MVLC-041-BN-TR

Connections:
+3V3: CON1.2, D3.C, R13.2, R16.2, R30.2, R33.2
+3V3LDO: C20.2, C22.2, C24.2, R31.2, U2.12 (VDDA), U2.20 (SSEL), U2.21 (MODE), U7.5 (OUT), Y1.1 (TRI_STATE), Y1.4 (VDD)
+12V: C3.1, C19.2, C23.2, CON1.15, D4.2 (A), D5.1 (K), D6.1 (K), K1.2, K2.2, L2.2, R4.2, U6.4 (VIN), U7.4 (IN)
/DEV_RX: CON1.8, U2.17 (RX/SDI)
/DEV_TX: CON1.7, U2.16 (TX/SDO)
/DO1: CON1.11, U2.13 (DO1)
/DO2: CON1.6, U2.14 (DO2)
/DO3: CON1.5, U2.15 (DO3)
/GPIO_Q1: CON1.3, R5.2
/GPIO_Q2: CON1.14, R7.2
/GPIO_S1: C5.2, CON1.4, R13.1, U3.4 (R)
/GPIO_S2: C6.2, CON1.13, R16.1, U4.4 (R)
/GPIO_S3: C16.2, CON1.12, R30.1, U5.4 (R)
/P_MEAS_RST: C15.2, CON1.10, R31.1, U2.2 (~RESET)
/REF_CLK: U2.1 (XIN), Y1.3 (OUTPUT)
AC_L: C2.2, C3.2, C5.1, C6.1, C7.1, C8.2, C9.1, C10.2, C11.1, C12.2, C14.2, C15.1, C16.1, C17.1, C18.1, C19.1, C20.1, C22.1, C23.1, C24.1, CON1.1, CON1.9, CON1.16, D1.2 (A), J2.3, J2.5, Q1.2 (S), Q2.2 (S), R4.1, R6.1, R8.1, R17.1, R18.2, R23.1, R25.1, R26.1, R28.1, R34.1, U2.11 (GNDA), U2.19 (~CS), U2.22 (GNDD), U3.3 (R), U4.3 (R), U5.3 (R), U6.2 (GND), U7.2 (GND), Y1.2 (GND)
AC_N: J2.6, R9.1, R22.1, U3.2 (K), U4.1 (A), U5.2 (K)
AC_Q1: J2.8, K1.5
AC_Q1_SHNT2: K1.8, R24.1, R25.2
AC_Q2: J2.1, K2.5
AC_Q2_SHNT2: K2.8, R26.2, R27.1
AC_S1: J2.7, R12.1
AC_S2: J2.2, R14.1
AC_S3: J2.4, R10.1
unnamed: C17.2, C18.2, D3.A, L4.2
unnamed: C1.2, C4.1, D1.1 (K), L2.1, R1.1, U1.5 (S), U1.6 (S), U1.7 (S), U1.8 (S)
unnamed: D2.2 (A), R9.2
unnamed: D2.1 (K), L1.1
unnamed: C4.2, D4.1 (K), R2.2, R3.2
unnamed: D5.2 (A), K1.1, Q1.3 (D)
unnamed: D6.2 (A), K2.1, Q2.3 (D)
unnamed: Q1.1 (G), R5.1, R6.2
unnamed: Q2.1 (G), R7.1, R8.2
unnamed: R10.2, R29.1
unnamed: R11.1, R12.2
unnamed: R14.2, R15.1
unnamed: R19.1, R20.2
unnamed: R20.1, R21.2
unnamed: R21.1, R22.2
unnamed: C1.1, R3.1, U1.1 (BP/M)
unnamed: C2.1, L1.2, U1.4 (D)
unnamed: R1.2, R2.1, U1.2 (FB)
unnamed: C12.1, R28.2, U2.4 (IIN1+)
unnamed: C11.2, R27.2, U2.3 (IIN1-)
unnamed: C10.1, R23.2, U2.8 (IIN2+)
unnamed: C9.2, R24.2, U2.7 (IIN2-)
unnamed: C14.1, U2.23 (VDDD)
unnamed: C7.2, R17.2, U2.5 (VIN+)
unnamed: C8.1, R18.1, R19.2, U2.6 (VIN-)
unnamed: C13.2, U2.10 (VREF+)
unnamed: C13.1, U2.9 (VREF-)
unnamed: R11.2, U3.1 (A)
unnamed: R15.2, U4.2 (K)
unnamed: R29.2, U5.1 (A)
unnamed: L4.1, U6.3 (PH)
unnamed: R33.1, R34.2, U6.5 (VSENSE)

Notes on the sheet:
Output 1 and output 2 relays control
High Voltage terminals
Power measurement
230VAC
Connection through HSSM-FCB with HSSM-LVPCB
Power converter DCDC 12V0->3V3
Power converter 230VAC -> 12VDC
Switch 1, switch 2 and switch 3 input circuitry

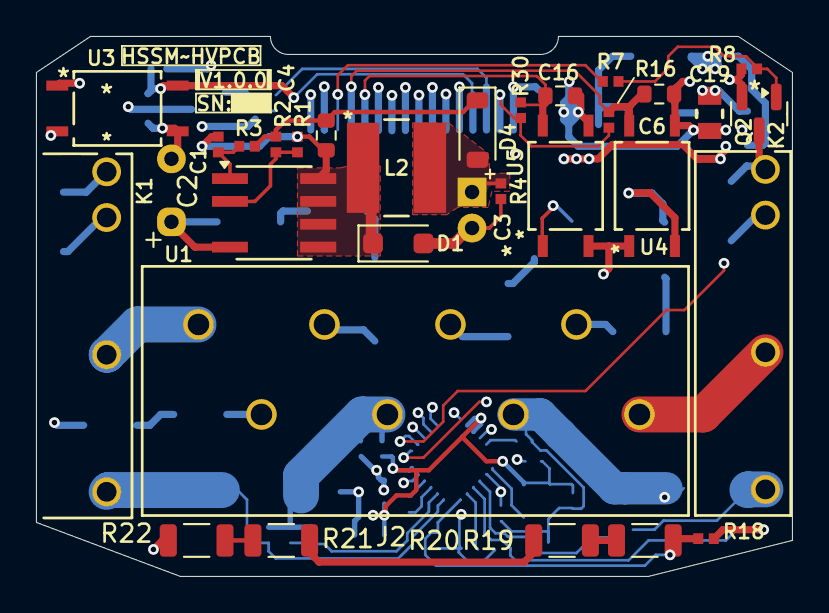
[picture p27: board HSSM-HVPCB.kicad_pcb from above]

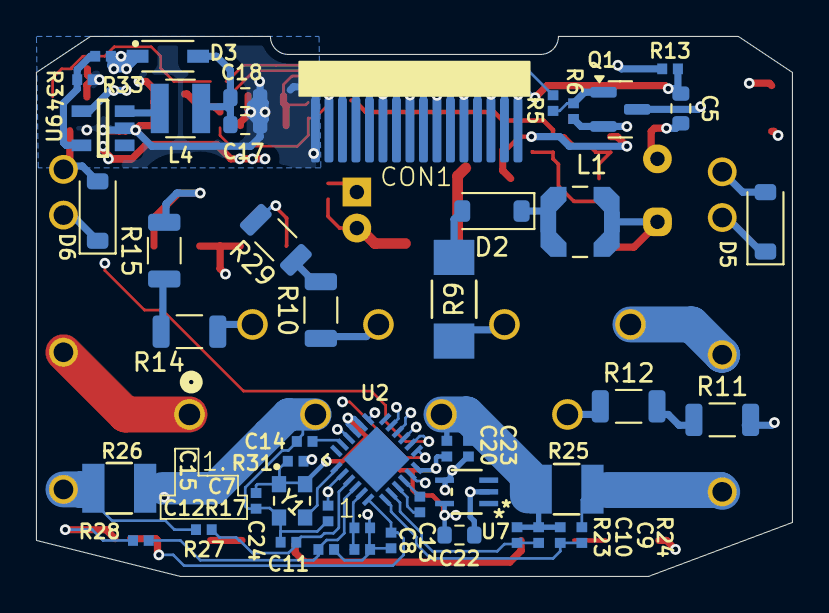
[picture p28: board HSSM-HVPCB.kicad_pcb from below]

Board: 4 copper layers, 42.0 x 30.0 mm, 79 parts (48 on the bottom side), 56 nets.

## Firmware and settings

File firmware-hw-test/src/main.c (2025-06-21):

// ###### - Imports - ###### 
#include <stdio.h>
#include "freertos/FreeRTOS.h"
#include "freertos/task.h"
#include "driver/gpio.h"

// ###### - GPIOs config - ###### 
#define PIN_D01         GPIO_NUM_7
#define PIN_D02         GPIO_NUM_0
#define PIN_D03         GPIO_NUM_3
#define PIN_LP_UART_RXD GPIO_NUM_10
#define PIN_LP_UART_TXD GPIO_NUM_11

#define PIN_GPIO_Q1     GPIO_NUM_18
#define PIN_GPIO_Q2     GPIO_NUM_10

#define PIN_S1_sym      GPIO_NUM_23
#define PIN_S2_sym      GPIO_NUM_1
#define PIN_S3_sym      GPIO_NUM_6

#define PIN_GPIO_S1     GPIO_NUM_19
#define PIN_GPIO_S2     GPIO_NUM_12
#define PIN_GPIO_S3     GPIO_NUM_5
#define PIN_S_set       GPIO_NUM_7

#define PIN_RGB_R       GPIO_NUM_22
#define PIN_RGB_G       GPIO_NUM_21
#define PIN_RGB_B       GPIO_NUM_20


// ###### - Main loop - ###### 
void app_main(void)
{
    // Configure the GPIOs
    gpio_reset_pin(PIN_S1_sym);
    gpio_reset_pin(PIN_S2_sym);
    gpio_reset_pin(PIN_S3_sym);
    gpio_set_direction(PIN_S1_sym, GPIO_MODE_INPUT);
    gpio_set_direction(PIN_S2_sym, GPIO_MODE_INPUT);
    gpio_set_direction(PIN_S3_sym, GPIO_MODE_INPUT);


    gpio_reset_pin(PIN_GPIO_Q1);
    gpio_reset_pin(PIN_GPIO_Q2);
    gpio_reset_pin(PIN_RGB_R);
    gpio_reset_pin(PIN_RGB_G);
    gpio_reset_pin(PIN_RGB_B);
    gpio_set_direction(PIN_GPIO_Q1, GPIO_MODE_OUTPUT);
    gpio_set_direction(PIN_GPIO_Q2, GPIO_MODE_OUTPUT);
    gpio_set_direction(PIN_RGB_R, GPIO_MODE_OUTPUT);
    gpio_set_direction(PIN_RGB_G, GPIO_MODE_OUTPUT);
    gpio_set_direction(PIN_RGB_B, GPIO_MODE_OUTPUT);


    gpio_set_level(PIN_RGB_R, 0);
    gpio_set_level(PIN_RGB_G, 0);
    gpio_set_level(PIN_RGB_B, 0);
    gpio_set_level(PIN_GPIO_Q1, 1);
    gpio_set_level(PIN_GPIO_Q2, 1);

    vTaskDelay(1000);

    while (1) {
        if(gpio_get_level(PIN_S1_sym)){
            gpio_set_level(PIN_GPIO_Q1, 1);
        }else{
            gpio_set_level(PIN_GPIO_Q1, 0);
        }

        if(gpio_get_level(PIN_S2_sym)){
            gpio_set_level(PIN_GPIO_Q2, 1);
        }else{
            gpio_set_level(PIN_GPIO_Q2, 0);
        }

        if(gpio_get_level(PIN_S3_sym)){
            gpio_set_level(PIN_RGB_R, 1);
            gpio_set_level(PIN_RGB_G, 1);
            gpio_set_level(PIN_RGB_B, 1);
        }else{
            gpio_set_level(PIN_RGB_R, 0);
            gpio_set_level(PIN_RGB_G, 0);
            gpio_set_level(PIN_RGB_B, 0);
        }

    }
}

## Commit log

2024-12-02 Add kicad project template
    [HSSM-HVPCB.kicad_pcb, HSSM-HVPCB.kicad_sch]
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2024-12-05 [#3] Add CS5480-INZ power meter
    [HSSM-HVPCB.kicad_sch]
2024-12-05 [#3] Add components to schematic
    [HSSM-HVPCB.kicad_sch]
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2024-12-09 [#3] SCH LNK3204 connections WIP
    [HSSM-HVPCB.kicad_sch]
2024-12-09 [#3] SCH LNK3204 connections
    [HSSM-HVPCB.kicad_sch]
2024-12-09 [#3] SCH LNK3204 connections correct output capacitor connection
    [HSSM-HVPCB.kicad_sch]
2024-12-09 [#3] Correct MURS160-E3/52T
    [HSSM-HVPCB.kicad_sch]
2024-12-09 [#3] SCH add relay control
    [HSSM-HVPCB.kicad_sch]
2024-12-10 [#3] SCH relay output
    [HSSM-HVPCB.kicad_sch]
2024-12-10 [#3] SCH add relay status leds
    [HSSM-HVPCB.kicad_sch]
2024-12-10 [#3] Correct LNK3204D-TL symbol MPN
    [HSSM-HVPCB.kicad_sch]
2024-12-10 [#3] Add S1 and S2 switch circuit
    [HSSM-HVPCB.kicad_sch]
2024-12-10 [#3] Add HV output terminals connections proposition
    [HSSM-HVPCB.kicad_sch]
2024-12-12 [#3] SCH power measuring - voltage measure
    [HSSM-HVPCB.kicad_sch]
2024-12-12 [#3] SCH power measuring - current measure on CH1
    [HSSM-HVPCB.kicad_sch]
2024-12-12 [#3] SCH power measuring - current measure on CH2
    [HSSM-HVPCB.kicad_sch]
2024-12-12 [#3] SCH power measuring - connect power pins
    [HSSM-HVPCB.kicad_sch]
2024-12-12 [#3] SCH power measuring - add oscillator
    [HSSM-HVPCB.kicad_sch]
2024-12-12 [#3] SCH power measuring - clean up
    [HSSM-HVPCB.kicad_sch]
2024-12-12 [#3] SCH add connector to LVPCB
    [HSSM-HVPCB.kicad_sch]
2024-12-13 [#3] SCH add surge protection
    [HSSM-HVPCB.kicad_sch]
2024-12-13 [#4] Add HSSM-LVPCB project
    [HSSM-LVPCB.kicad_pcb, HSSM-LVPCB.kicad_sch]
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2024-12-15 [#3] SCH add 12V0 to 3V3 power converter
    [HSSM-HVPCB.kicad_sch]
2024-12-16 [#5] Correct power measurement connection, make L wire GND
    [HSSM-HVPCB.kicad_sch]
2024-12-16 [#3] Replace DCDC converter with TPS560200DBVR
    [HSSM-HVPCB.kicad_sch]
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2024-12-17 [#4] SCH ESP32-C6 WIP
    [HSSM-LVPCB.kicad_sch]
2024-12-17 [#4] SCH ESP32-C6 add flash memory
    [HSSM-LVPCB.kicad_sch]
2024-12-18 [#4] SCH replace crystal oscillator with more stagble one
    [HSSM-LVPCB.kicad_sch]
2024-12-18 [#4] SCH add USB UART converter as programmer
    [HSSM-LVPCB.kicad_sch]
2024-12-20 [#4] SCH add RGB LED
    [HSSM-LVPCB.kicad_sch]
2024-12-21 [#4] SCH add usr btn
    [HSSM-LVPCB.kicad_sch]
2024-12-22 [#4] SCH Add board to board connections
    [HSSM-LVPCB.kicad_sch]
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2024-12-30 [#6] BRD import all updated footprints to PCB
    [HSSM-HVPCB.kicad_pcb, HSSM-HVPCB.kicad_sch]
2024-12-30 [#6] Update step models
    [HSSM-HVPCB.kicad_pcb, HSSM-HVPCB.kicad_sch]
2024-12-30 [#6] Add step model for SDR0503-102KL
    [HSSM-HVPCB.kicad_pcb]
2024-12-30 [#6] Add step model for LPS4012-155MRC
    [HSSM-HVPCB.kicad_pcb]
2024-12-30 [#6] Add step model R_0402
    [HSSM-HVPCB.kicad_pcb]
2024-12-30 [#6] Add step model C_0402
    [HSSM-HVPCB.kicad_pcb]
2024-12-30 [#6] Fix step model R 1206
    [HSSM-HVPCB.kicad_pcb]
2024-12-30 [#6] Add board outline
    [HSSM-HVPCB.kicad_pcb]
2024-12-30 [#6] Remove 3pin terminal
    [HSSM-HVPCB.kicad_sch]
2024-12-30 [#6] Remove RGB LED
    [HSSM-HVPCB.kicad_sch]
2024-12-30 [#6] Remove surge protection
    [HSSM-HVPCB.kicad_sch]
2024-12-30 [#6] Replace wago terminal with 8 pos variant
    [HSSM-HVPCB.kicad_pcb, HSSM-HVPCB.kicad_sch]
2024-12-30 [#7] Components placement WIP
    [HSSM-HVPCB.kicad_pcb]
2024-12-31 [#6] Replace crystal oscillator
    [HSSM-HVPCB.kicad_pcb, HSSM-HVPCB.kicad_sch]
2025-01-02 [#6] Remove status LEDs from HVPCB
    [HSSM-HVPCB.kicad_pcb, HSSM-HVPCB.kicad_sch]
2025-01-02 [#6] Add L 3012
    [HSSM-HVPCB.kicad_pcb]
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2025-01-02 [#7] Placement WIP 12VDC->3V3DC
    [HSSM-HVPCB.kicad_pcb]
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2025-01-03 [#4] Add S1, S2, S3 buttons
    [HSSM-LVPCB.kicad_sch]
2025-01-03 [#4] Add green LED
    [HSSM-LVPCB.kicad_sch]
2025-01-03 [#4] Add status LEDs for inputs and outputs
    [HSSM-LVPCB.kicad_sch]
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2025-01-03 [#4] SCH add BME280
    [HSSM-LVPCB.kicad_sch]
2025-01-03 [#4] SCH add ENS160
    [HSSM-LVPCB.kicad_sch]
2025-01-03 [#4] SCH add note for ENS160
    [HSSM-LVPCB.kicad_sch]
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2025-01-04 [#4] Replace board-to-board connector
    [HSSM-LVPCB.kicad_sch]
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2025-01-04 [#8] Add L 0402
    [HSSM-LVPCB.kicad_pcb, HSSM-LVPCB.kicad_sch]
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2025-01-04 [#8] Update symbols and import footprints to PCB
    [HSSM-LVPCB.kicad_pcb, HSSM-LVPCB.kicad_sch]
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2025-01-04 [#9] Replace switches
    [HSSM-LVPCB.kicad_pcb, HSSM-LVPCB.kicad_sch]
2025-01-04 [#9] Replace LEDs
    [HSSM-LVPCB.kicad_pcb, HSSM-LVPCB.kicad_sch]
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2025-01-07 [#7] Replace capacitors in DCDC converter
    [HSSM-HVPCB.kicad_pcb, HSSM-HVPCB.kicad_sch]
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2025-01-08 [#3] SCH replace fusible resistor with SMD
    [HSSM-HVPCB.kicad_pcb, HSSM-HVPCB.kicad_sch]
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2025-01-10 [#11] Add vias for easier soldering and adjusted FCB size
    [HSSM-FCB.kicad_pcb]
2025-01-10 [#12] PCB Add netclass for high voltage signals
    [HSSM-HVPCB.kicad_pcb, HSSM-HVPCB.kicad_sch]
2025-01-10 [#12] PCB Add netclass for high current paths
    [HSSM-HVPCB.kicad_pcb, HSSM-HVPCB.kicad_sch]
2025-01-10 [#12] PCB Correct 230VAC clearance setting
    [HSSM-HVPCB.kicad_pcb, HSSM-HVPCB.kicad_sch]
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2025-01-10 [#12] PCB Add custom DRC rules for HV internal layers
    [HSSM-HVPCB.kicad_pcb]
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2025-01-10 [#12] PCB Routing WIP swaped opto insulation HV inputs
    [HSSM-HVPCB.kicad_pcb, HSSM-HVPCB.kicad_sch]
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2025-01-16 [#13] PCB routing WIP decreased size of all vias
    [HSSM-LVPCB.kicad_pcb]
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2025-01-19 [#12] PCB routing WIP reconnected shunt resistors to better fit layout
    [HSSM-HVPCB.kicad_pcb, HSSM-HVPCB.kicad_sch]
2025-01-21 [#13] Add oscillator CN4040M00010001
    [HSSM-LVPCB.kicad_pcb, HSSM-LVPCB.kicad_sch]
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2025-01-21 [#13] Correct crystal
    [HSSM-LVPCB.kicad_pcb, HSSM-LVPCB.kicad_sch]
2025-01-21 [#13] Change stackup to JLCPCB - no requirement and correct antenna traces width to match 50ohm
    [HSSM-LVPCB.kicad_pcb]
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2025-01-21 [#13] PCB Add name, version and serial number on silkscreen
    [HSSM-LVPCB.kicad_pcb]
2025-01-21 [#13] PCB minor fixes
    [HSSM-LVPCB.kicad_pcb]
2025-01-21 [#13] PCB fix DRC
    [HSSM-LVPCB.kicad_pcb]
2025-01-21 Fix outline, add board info and sn on silkscreen
    [HSSM-FCB.kicad_pcb]
2025-01-21 [#13] PCB minor corrections to traces
    [HSSM-LVPCB.kicad_pcb]
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2025-01-22 [#14] SCH Add LDO for powering power measurement IC
    [HSSM-HVPCB.kicad_sch]
2025-01-22 [#14] SCH add diode on 3V3 DCDC output
    [HSSM-HVPCB.kicad_sch]
2025-01-22 [#12] PCB Add name, rev and sn on silkscreen
    [HSSM-HVPCB.kicad_pcb]
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2025-01-23 [#15] Add more GND vias under ESP32-C6 chip
    [HSSM-LVPCB.kicad_pcb]
2025-01-23 [#15] Reposition RF RLC to match pi circuit
    [HSSM-LVPCB.kicad_pcb]
2025-01-23 [#15] Modify C1 layout as specified in hardware design guide
    [HSSM-LVPCB.kicad_pcb]
2025-01-23 [#15] Fix traces around RF part
    [HSSM-LVPCB.kicad_pcb]
2025-01-23 [#15] Add keepout and reference plane under U FL connector
    [HSSM-LVPCB.kicad_pcb]
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2025-01-23 [#15] Removed unecessary GND cutout from U Fl connector
    [HSSM-LVPCB.kicad_pcb]
2025-01-23 [#15] Fix DRC
    [HSSM-LVPCB.kicad_pcb]
2025-01-23 [#14] WIP fixing DCDC converter placement
    [HSSM-HVPCB.kicad_pcb]
2025-01-23 [#14] fix DCDC converter
    [HSSM-HVPCB.kicad_pcb]
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2025-03-04 HVPCB replace oscillator
    [HSSM-HVPCB.kicad_pcb, HSSM-HVPCB.kicad_sch]
2025-03-06 Replace shunt resistors
    [HSSM-HVPCB.kicad_pcb, HSSM-HVPCB.kicad_sch]
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2025-03-09 PCB 499R change footprint to recommended by datasheet
    [HSSM-HVPCB.kicad_pcb, HSSM-HVPCB.kicad_sch]
2025-03-09 PCB DRC Errors
    [HSSM-HVPCB.kicad_pcb, HSSM-HVPCB.kicad_sch]
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2025-03-09 Minor fixes to HSSM LVPCB
    [HSSM-LVPCB-B_Cu.gbr, HSSM-LVPCB-B_Mask.gbr, HSSM-LVPCB-B_Paste.gbr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]
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2025-06-15 Fix missing 3V3 voltages
    [HSSM-LVPCB.kicad_pcb, HSSM-LVPCB.kicad_sch]
2025-06-16 HVPCB Replace D1 diode
    [HSSM-HVPCB.kicad_sch]
2025-06-16 LVPCB replace 2nH coil
    [HSSM-LVPCB.kicad_pcb, HSSM-LVPCB.kicad_sch]
2025-06-16 LVPCB replace SPI serial flash
    [HSSM-LVPCB.kicad_pcb, HSSM-LVPCB.kicad_sch]
2025-06-17 Add missing capacitors step models
    [HSSM-HVPCB.kicad_pcb]
2025-06-17 LVPCB add missing step models
    [HSSM-LVPCB.kicad_pcb, HSSM-LVPCB.kicad_sch]
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2025-06-17 LVPCB fix vias
    [HSSM-LVPCB.kicad_pcb]
2025-06-17 HSSM-HVPCB add missing step models
    [HSSM-HVPCB.kicad_pcb]
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2025-06-21 Replace WSON-8-1EP_6x5mm_P1_27mm_EP3_4x4_3mm.step to step
    [HSSM-LVPCB.kicad_pcb]
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

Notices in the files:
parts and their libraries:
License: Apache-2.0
